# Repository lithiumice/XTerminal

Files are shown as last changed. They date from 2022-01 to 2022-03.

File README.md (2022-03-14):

## 说明
- 模拟器工程在XTerminal\2.Software\XTerminal-ESP32-simulator
- 模拟器工程使用Visual Studio 2019
- 代码工程在XTerminal\2.Software\XTerminal-ESP32-simulator
- 代码工程基于Platformio

#
PCB在项目工程的1.Hardware中，使用Kicad绘制。分为主控板和音频板，两者的硬件连接没有设计好，实际焊接为了便于组装就用了粗一点的飞线把主控板和音频板上的sd卡引脚和音频信号引脚连了起来，我只做了临时的用于验证的一个版本，后面没有心情完善了，只能说这只用于抛砖引玉。
#

#### 主控板焊接
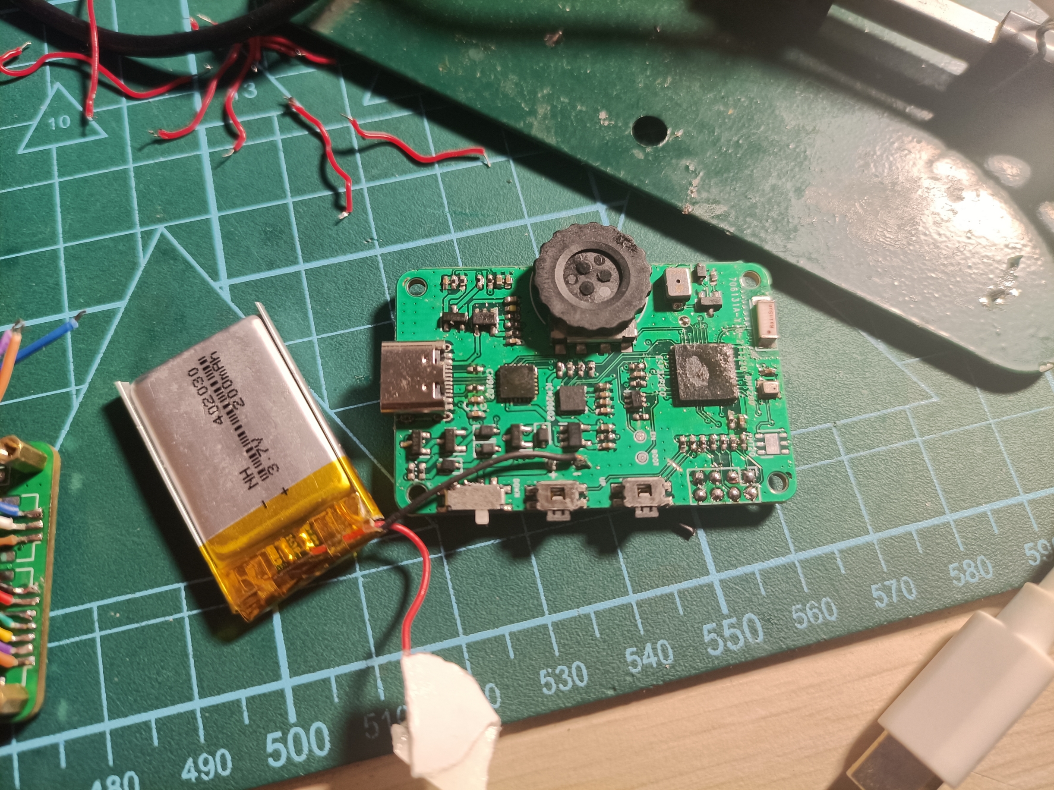
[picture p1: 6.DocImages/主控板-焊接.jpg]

#### 音频板焊接
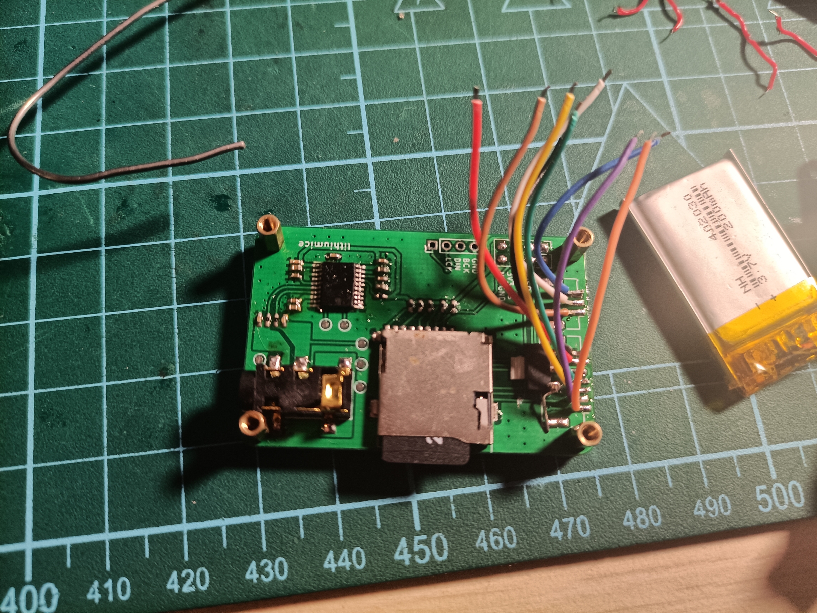
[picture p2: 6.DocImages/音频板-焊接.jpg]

#### 焊接和组装完成的成品效果：
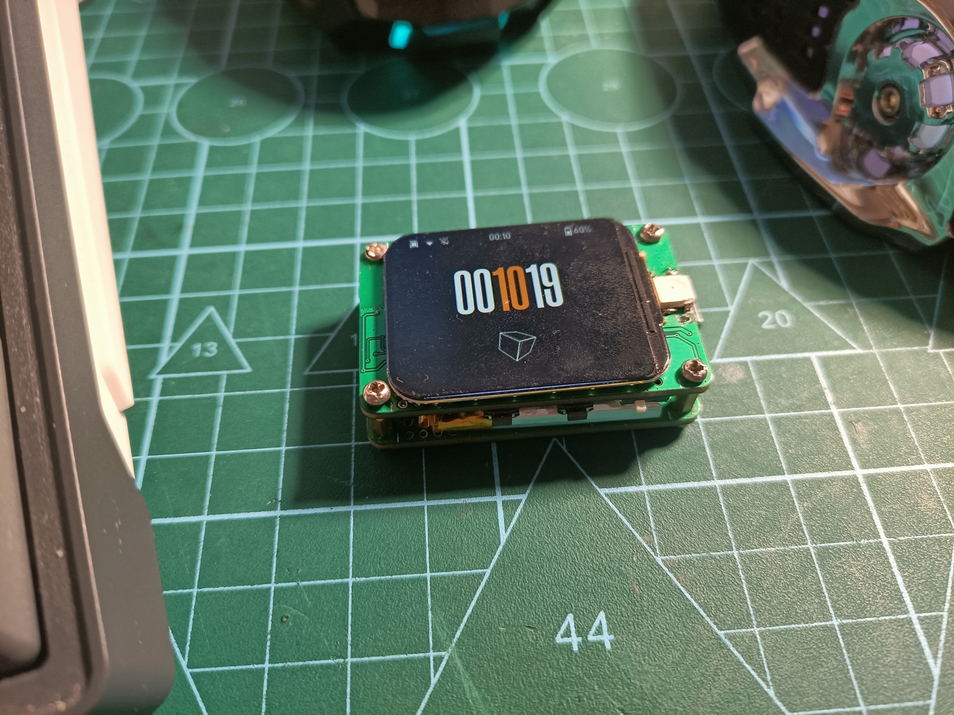
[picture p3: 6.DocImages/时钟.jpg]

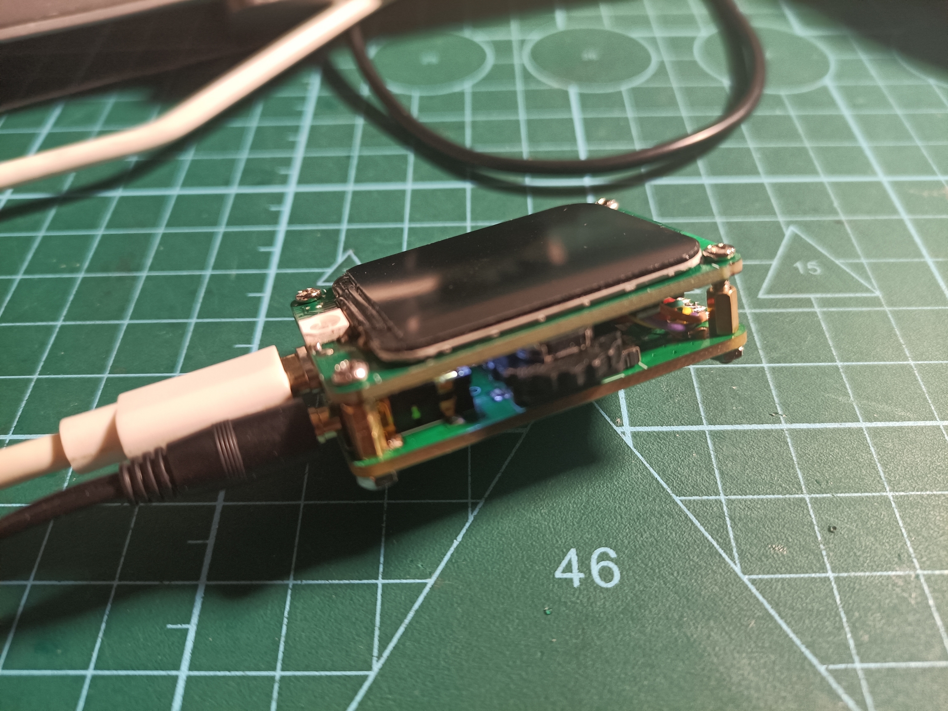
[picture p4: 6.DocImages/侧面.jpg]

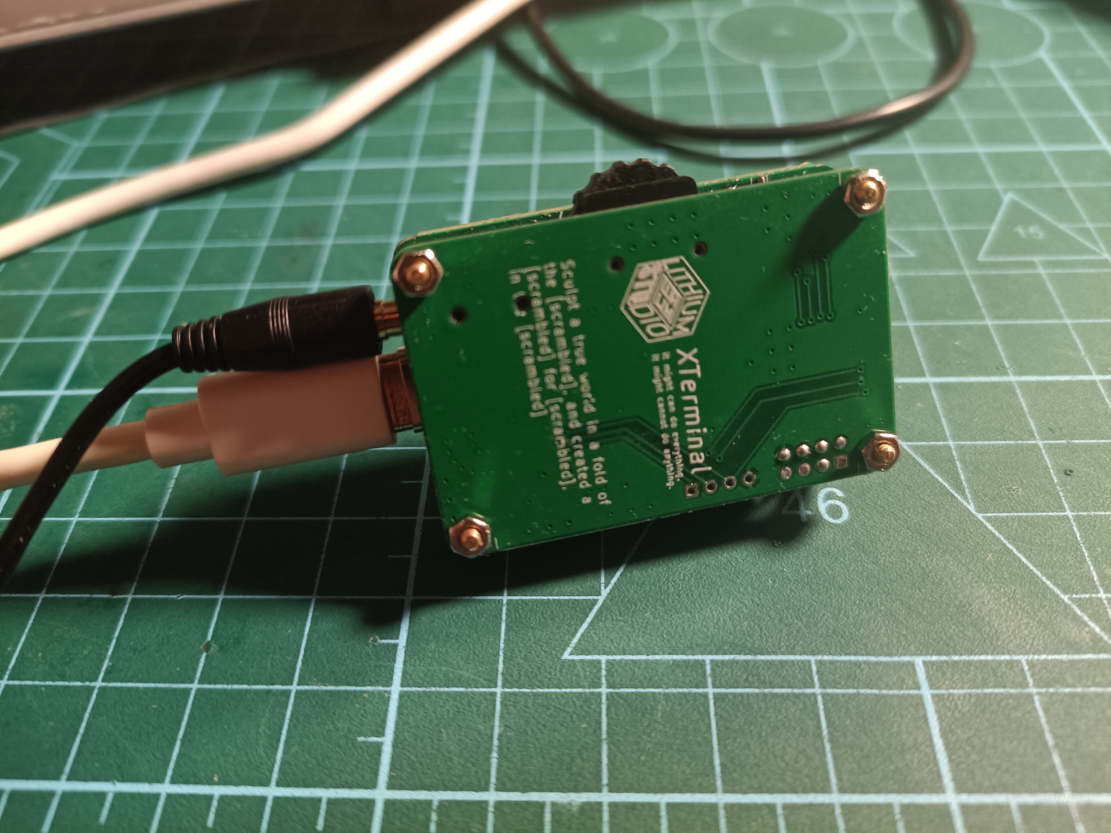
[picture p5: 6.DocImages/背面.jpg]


#### 主界面：（没拍实物图，就只好放模拟器的截图了）
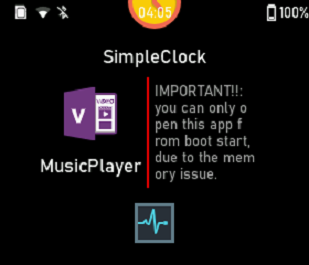
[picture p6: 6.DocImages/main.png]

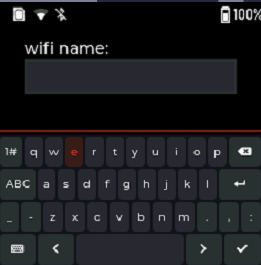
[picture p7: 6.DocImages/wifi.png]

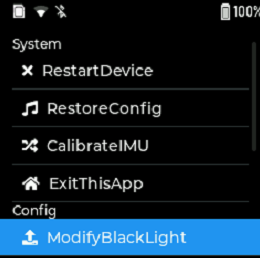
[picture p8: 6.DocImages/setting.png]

#### 天气显示：
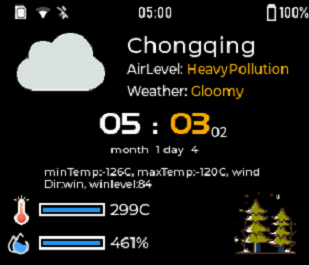
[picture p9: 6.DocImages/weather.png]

#### 几个Arduboy小游戏
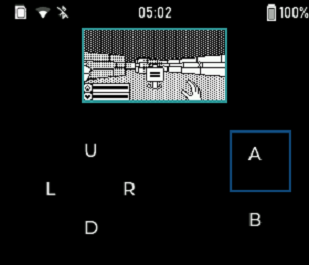
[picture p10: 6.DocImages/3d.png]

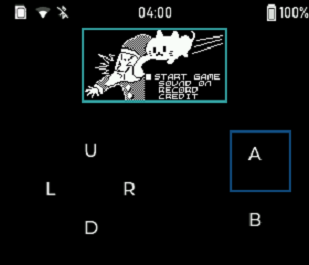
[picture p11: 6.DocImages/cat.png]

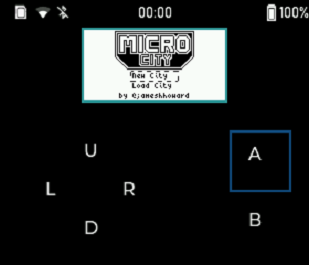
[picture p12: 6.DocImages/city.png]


#### PCB示例
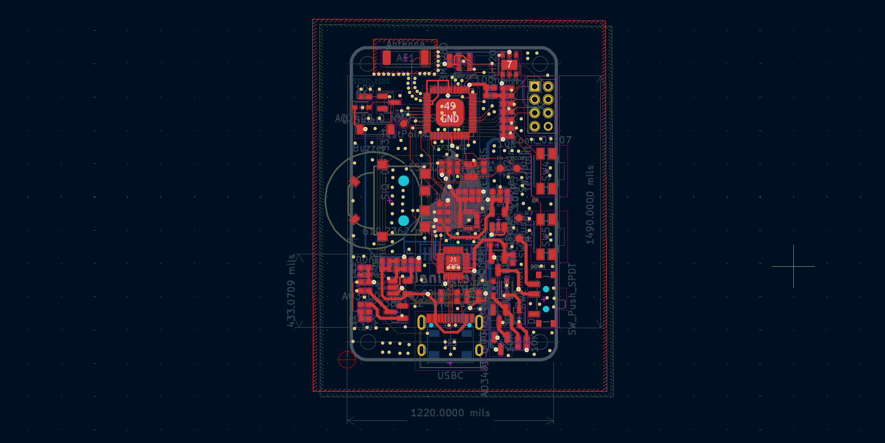
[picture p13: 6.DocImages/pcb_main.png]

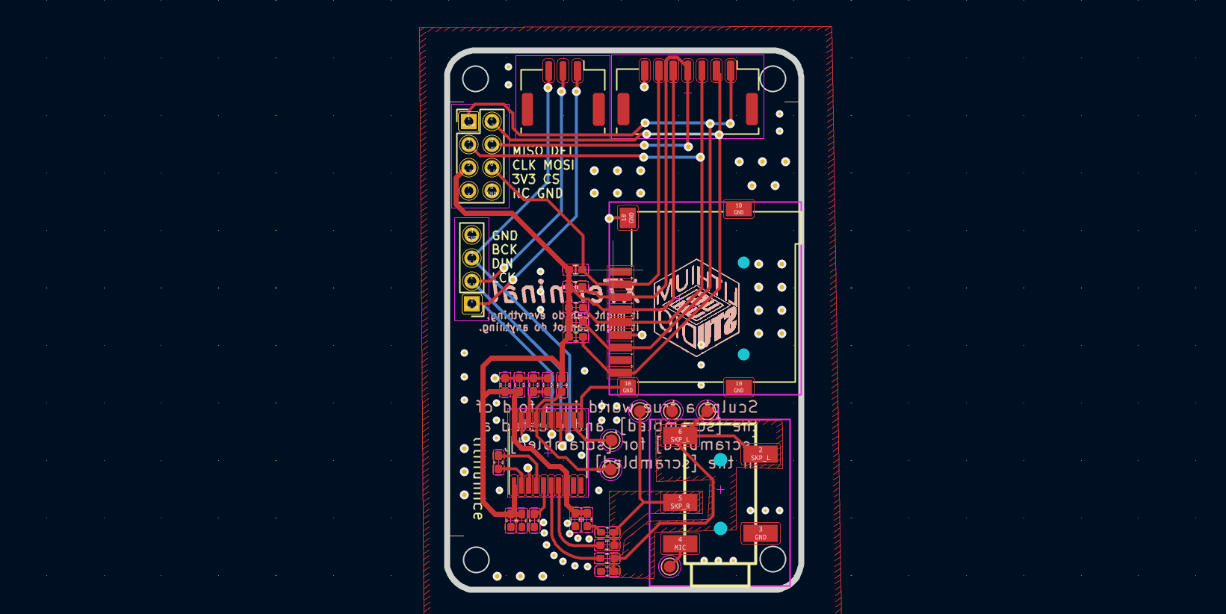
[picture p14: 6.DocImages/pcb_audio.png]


#### 原理图示例
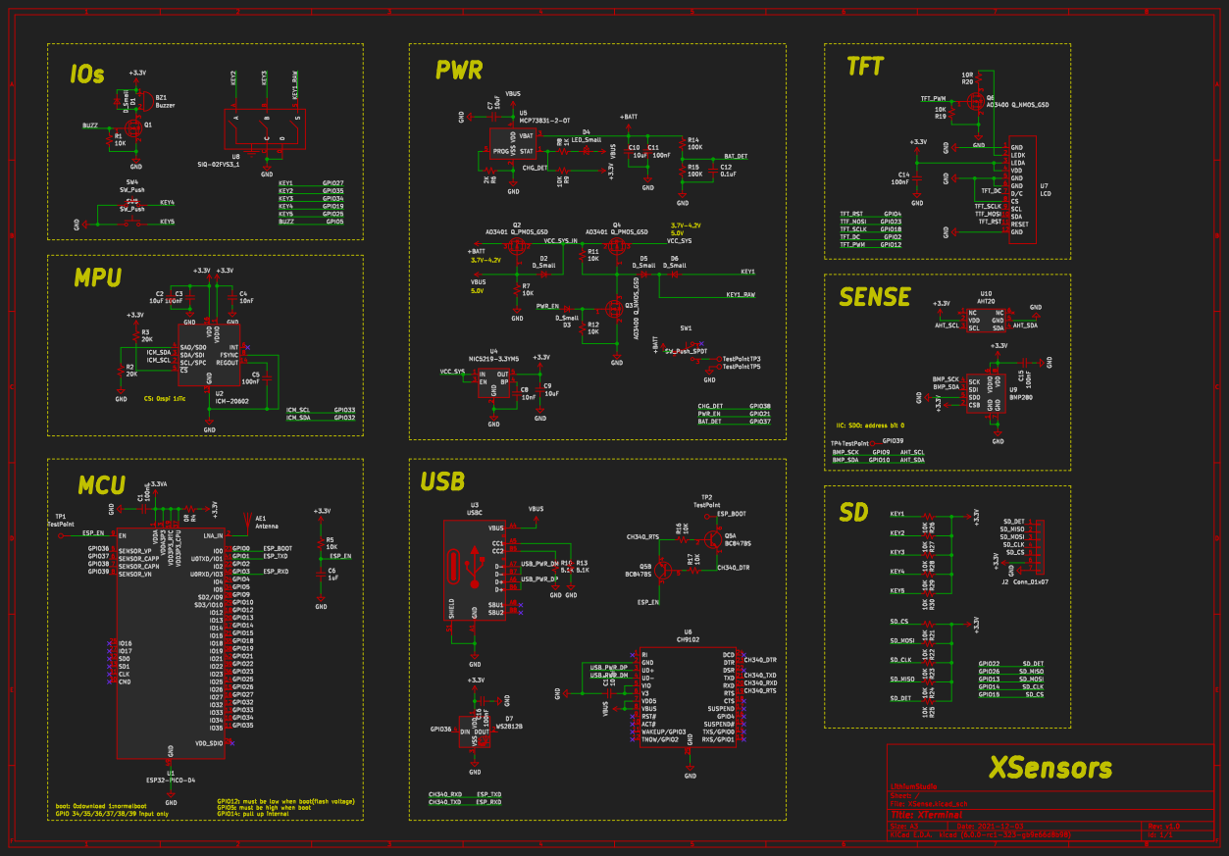
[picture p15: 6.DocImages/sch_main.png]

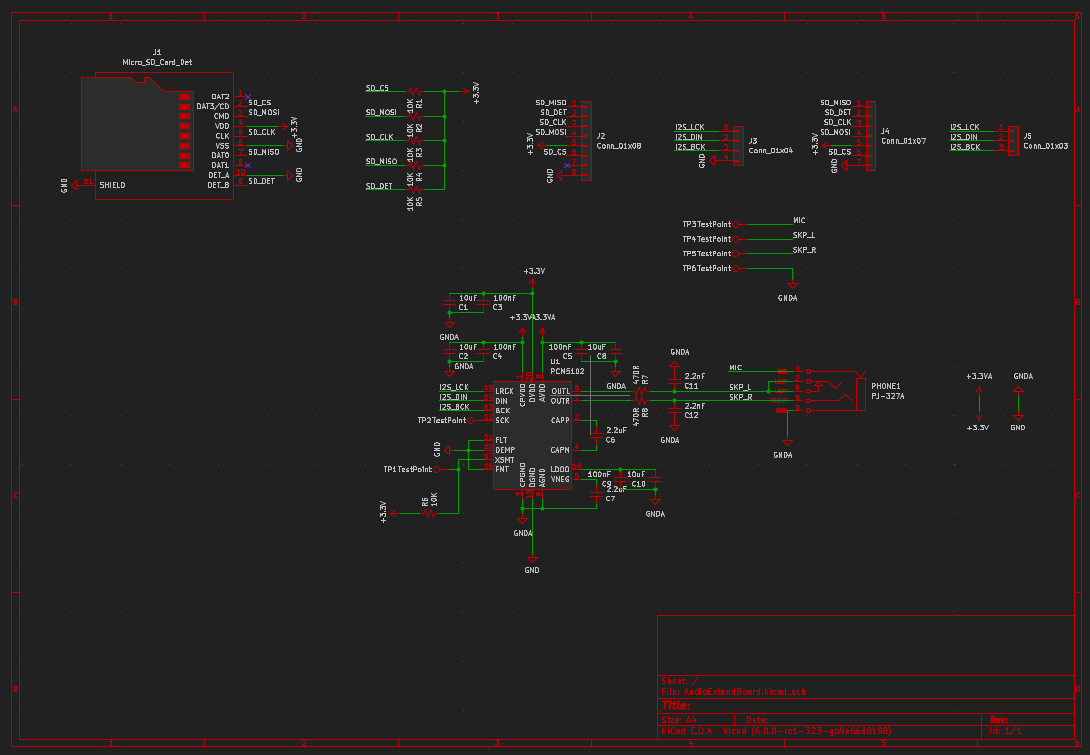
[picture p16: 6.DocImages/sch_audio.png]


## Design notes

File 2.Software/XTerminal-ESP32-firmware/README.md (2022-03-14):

device 0:
esp32-pico-d4
st7789 240x240
encoder keys

device 1:
esp32-pico-d4
st7789 240x280
3axis keys
max30102

devoce 2:
esp-wrover32
ili9341 240x320
pcf keys

devoce 3:
esp-wroom32
st7789 240x320
pcf keys

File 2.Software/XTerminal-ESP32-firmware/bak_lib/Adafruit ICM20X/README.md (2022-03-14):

# Adafruit ICM20X Documentation

This is the Adafruit ICM20X Arduino Library for use with the TDK Invensense ICM20649 and ICM20948 motion sensors.

### Tested and works great with the following Adafruit ICM20X Family Breakout Boards:

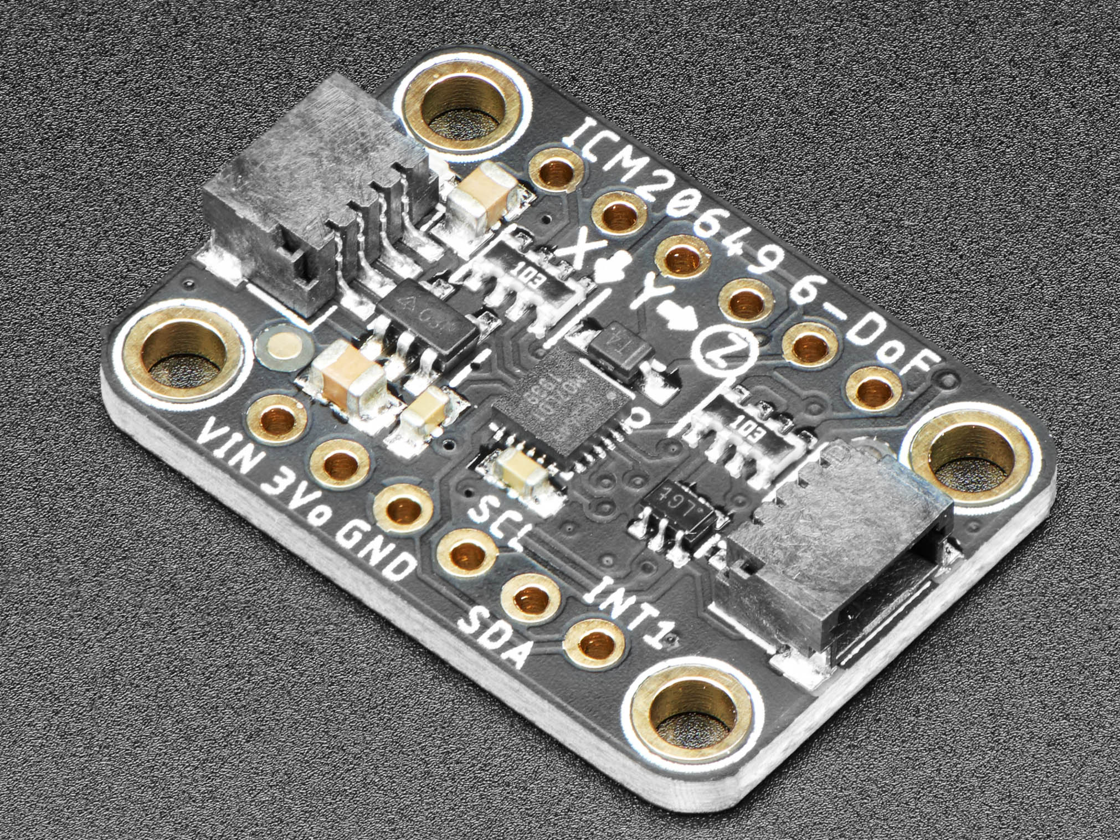
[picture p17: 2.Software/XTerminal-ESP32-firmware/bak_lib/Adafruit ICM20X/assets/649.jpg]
[](https://www.adafruit.com/products/4464)
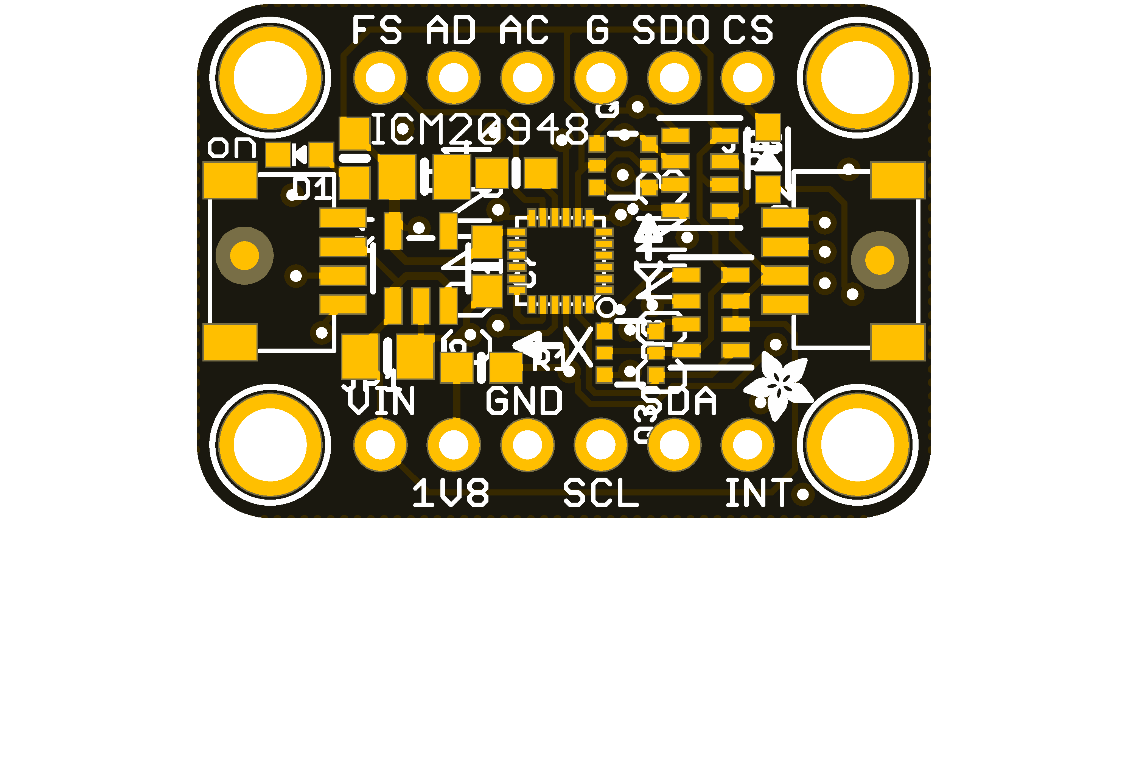
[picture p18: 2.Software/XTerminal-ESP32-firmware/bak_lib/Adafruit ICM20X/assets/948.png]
[](https://www.adafruit.com/products/4554)

#### Compatible sensor breakouts available in the Adafruit store:
* [Adafruit ICM-20649 Wide Range ±30g ±4000dps 6-DoF IMU](https://www.adafruit.com/products/4464)
* [Adafruit ICM-20948 9-DoF IMU](https://www.adafruit.com/products/4554)

Adafruit invests time and resources providing this open source code, please support Adafruit and open-source hardware by purchasing products from Adafruit!

# Installation
To install, use the Arduino Library Manager and search for "Adafruit ICM20X" and install the library.

## Dependencies
 * [Adafruit BusIO](https://github.com/adafruit/Adafruit_BusIO)
 * [Adafruit Unified Sensor Driver](https://github.com/adafruit/Adafruit_Sensor)

# Contributing

Contributions are welcome! Please read our [Code of Conduct](https://github.com/adafruit/Adafruit_ICM20X/blob/master/CODE_OF_CONDUCT.md>)
before contributing to help this project stay welcoming.

## Documentation and doxygen
Documentation is produced by doxygen. Contributions should include documentation for any new code added.

Some examples of how to use doxygen can be found in these guide pages:

https://learn.adafruit.com/the-well-automated-arduino-library/doxygen

https://learn.adafruit.com/the-well-automated-arduino-library/doxygen-tips

## Formatting and clang-format
This library uses [`clang-format`](https://releases.llvm.org/download.html) to standardize the formatting of `.cpp` and `.h` files. 
Contributions should be formatted using `clang-format`:

The `-i` flag will make the changes to the file.
```bash
clang-format -i *.cpp *.h
```
If you prefer to make the changes yourself, running `clang-format` without the `-i` flag will print out a formatted version of the file. You can save this to a file and diff it against the original to see the changes.

Note that the formatting output by `clang-format` is what the automated formatting checker will expect. Any diffs from this formatting will result in a failed build until they are addressed. Using the `-i` flag is highly recommended.

### clang-format resources
  * [Binary builds and source available on the LLVM downloads page](https://releases.llvm.org/download.html)
  * [Documentation and IDE integration](https://clang.llvm.org/docs/ClangFormat.html)

## About this Driver
Written by Bryan Siepert for Adafruit Industries.
BSD license, check license.txt for more information
All text above must be included in any redistribution

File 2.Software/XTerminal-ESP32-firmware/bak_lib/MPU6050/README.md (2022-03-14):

# I2CDEV_MPU6050
I2CDEV MPU-6050 6-axis accelerometer/gyroscope Arduino Library
adapted for Particle devices by Paul Kourany, April 2015

Updated to Particle Libraries v2.0, March 24, 2017

The MPU6050 combines a 3-axis gyroscope and a 3-axis accelerometer on the same silicon die together with
an onboard Digital Motion Processor(DMP) which processes complex 6-axis MotionFusion algorithms.

Original Library
----------------
https://github.com/jrowberg/i2cdevlib/tree/master/Arduino/MPU6050

I2CDevlib Website Link
----------------------
http://www.i2cdevlib.com/devices/mpu6050#source

Installing in the Spark.io Web IDE
----------------------------------

1. Open the Web based IDE on the Spark.io website.
2. Click on the Library button on the left hand side of the IDE. It looks like a little banner or flag...
3. Click "Contribute Library" button at the top of the panel that folded out.
4. Paste "JamesHagerman/MPU6050" into the text field (without quotes, of course).
5. Click "Add Repository".
6. Make sure the main window in the IDE says "Library is valid. Ready to import." at the top.
7. Click "Import".
8. Click "Got it, Proceed" if it asks you. This is basically because the True MPU6050 library is already there (but it's broken otherwise you wouldn't be reading this...)
9. You're done!

Look at the next section to actually use the library in a project. The "Use this example" button doesn't work with this library quite yet.

Using the library on the Spark.io Web IDE
-----------------------------------------

1. Create a new project in the Web based IDE on the Spark.io website. Remember the name for step 6.
2. Click the Library button the left hand side of the IDE. It still looks like a little banner or flag...
3. Select the MPU6050 Library from under the "My Libraries" section.
4. Make sure the version is at least "1.0.1"
5. Click "Include in App"
6. Select the app you just created (or whatever app you wanna use this library in)
7. Click "Add to this App"
8. You're done!

Now you just need some example code, right? You can find a (hopefully) working example at:
```
examples/spark_ide_example.c
```

You'll probably need to modify it pretty heavily to get it to do what you wanna do but at least it's spitting out data now!

Good luck!

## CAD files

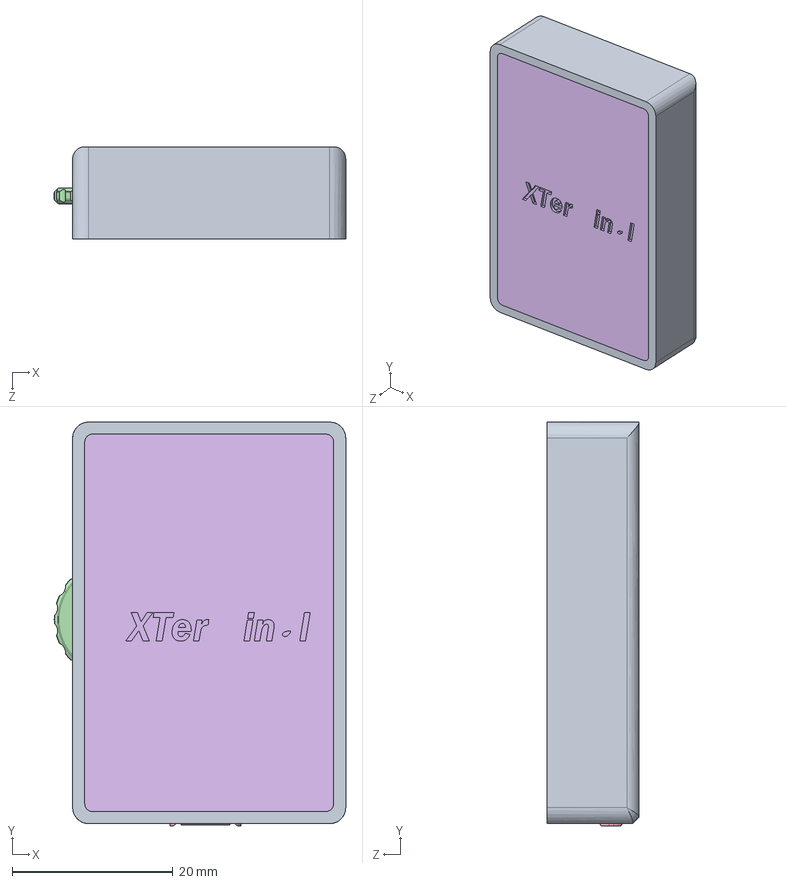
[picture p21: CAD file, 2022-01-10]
3.Mechanic/Xtermianl-280x240-Mechanical/总装配.SLDASM
36.3 x 50.3 x 11.5 mm
PCB外壳
屏幕
电路板
编码器
USB
背板

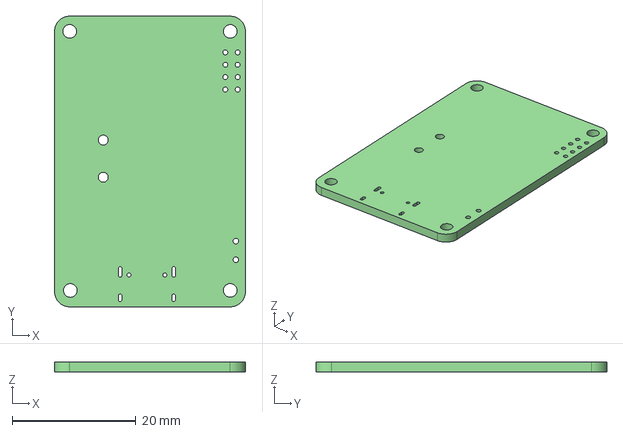
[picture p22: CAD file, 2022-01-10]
1.Hardware/Xtermianl-280x240-Kicad6/XSense.step
30.8 x 46.9 x 1.60 mm

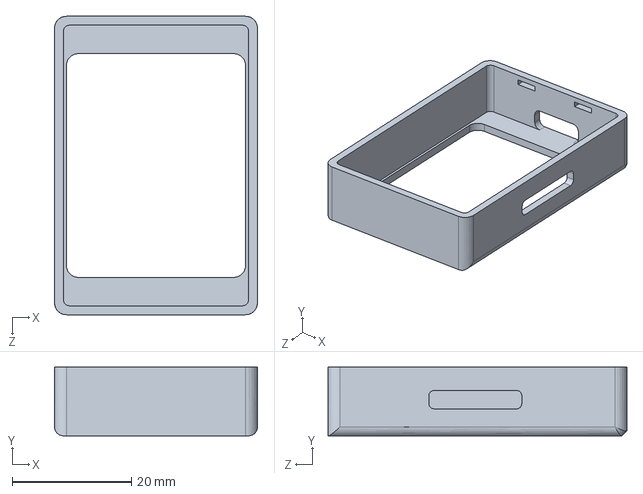
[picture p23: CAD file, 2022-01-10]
3.Mechanic/Xtermianl-280x240-Mechanical/PCB外壳.SLDPRT
34.0 x 11.5 x 50.0 mm

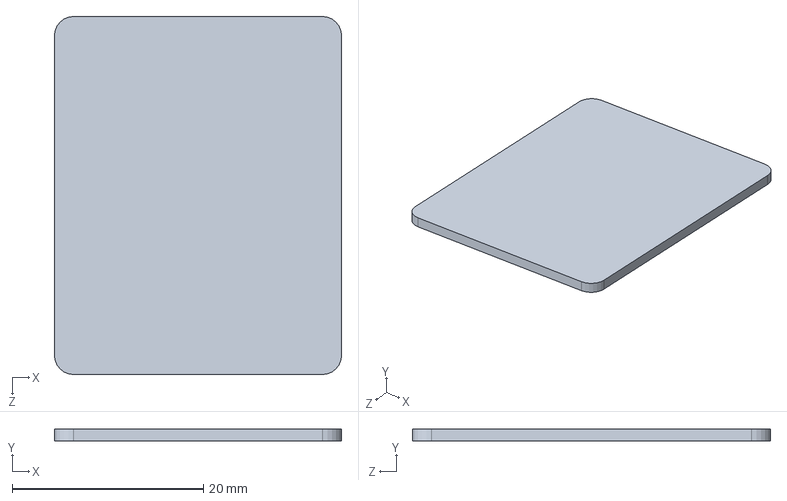
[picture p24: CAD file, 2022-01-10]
3.Mechanic/Xtermianl-280x240-Mechanical/屏幕.SLDPRT
30.0 x 1.30 x 37.4 mm

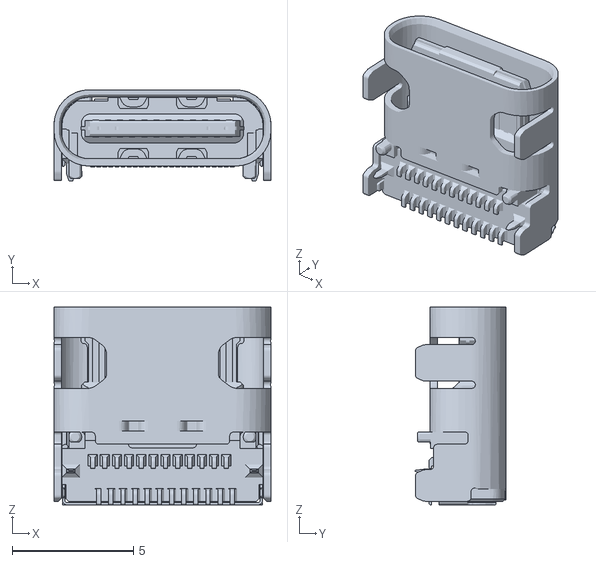
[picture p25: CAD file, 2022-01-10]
3.Mechanic/Xtermianl-280x240-Mechanical/typec.stl
8.94 x 3.77 x 8.15

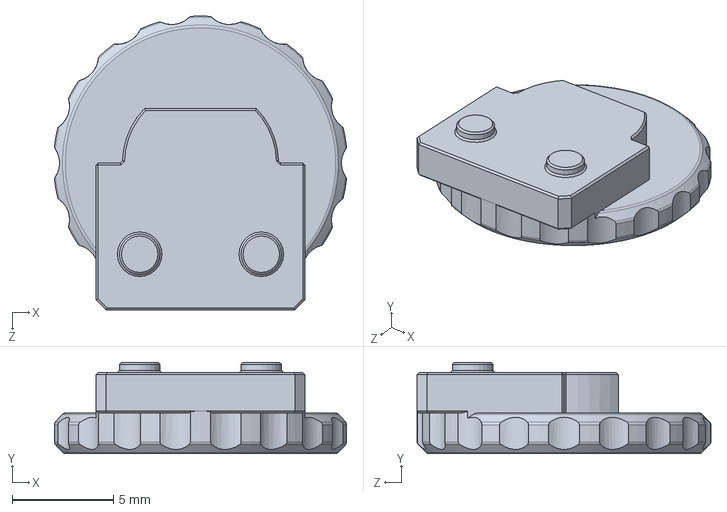
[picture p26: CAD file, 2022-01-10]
3.Mechanic/Xtermianl-280x240-Mechanical/编码器.SLDPRT
14.4 x 4.50 x 14.5 mm

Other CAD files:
3.Mechanic/Xtermianl-280x240-Mechanical/c-2295018-2-b-3d.stp.SLDPRT
3.Mechanic/Xtermianl-280x240-Mechanical/电路板.SLDPRT

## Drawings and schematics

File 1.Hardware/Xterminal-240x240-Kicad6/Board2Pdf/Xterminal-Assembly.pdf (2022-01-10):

BOOT | EN MID + - UP | KEYA DOWN 1 | 2 | 3 | 4 | 5 | 6 1 | 2 | 3 | 4 | 5 | 6 ABCD | ABCD Date: KiCad E.D.A. kicad (6.0.0-rc1-323-gb9e66d8b98) Size: A4 | Rev:

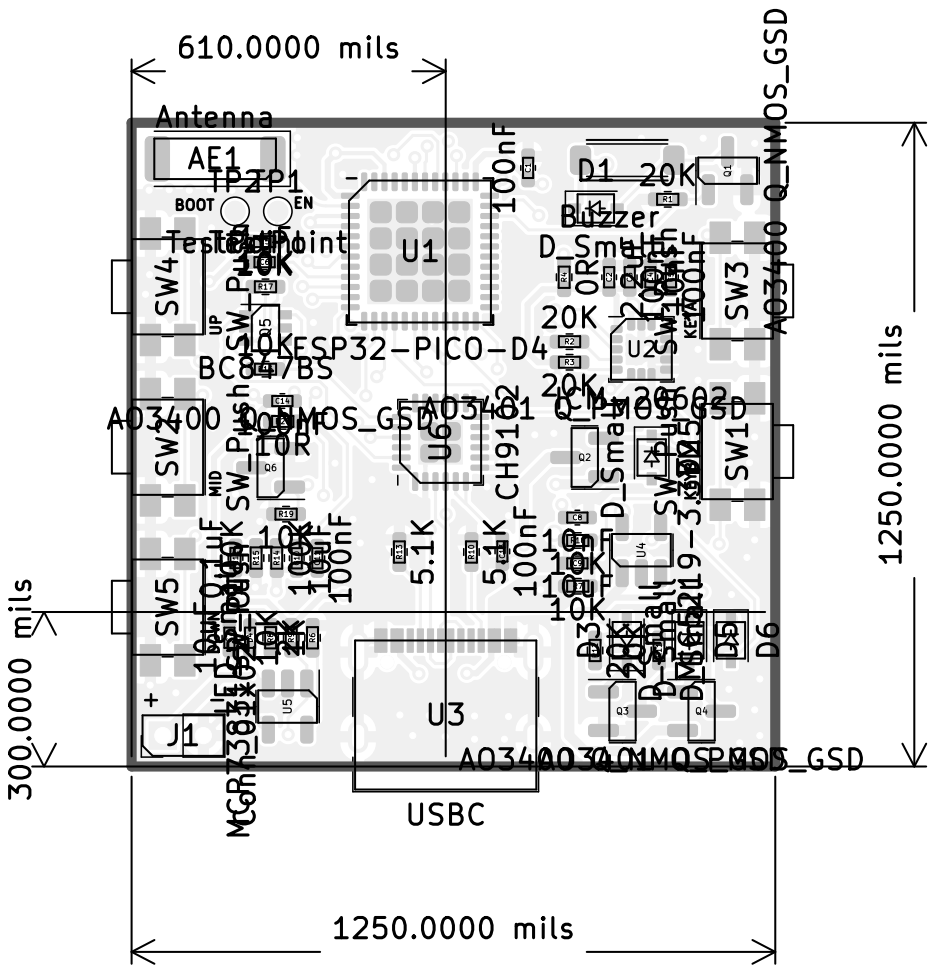
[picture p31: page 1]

1 | 2 | 3 | 4 | 5 | 6

A

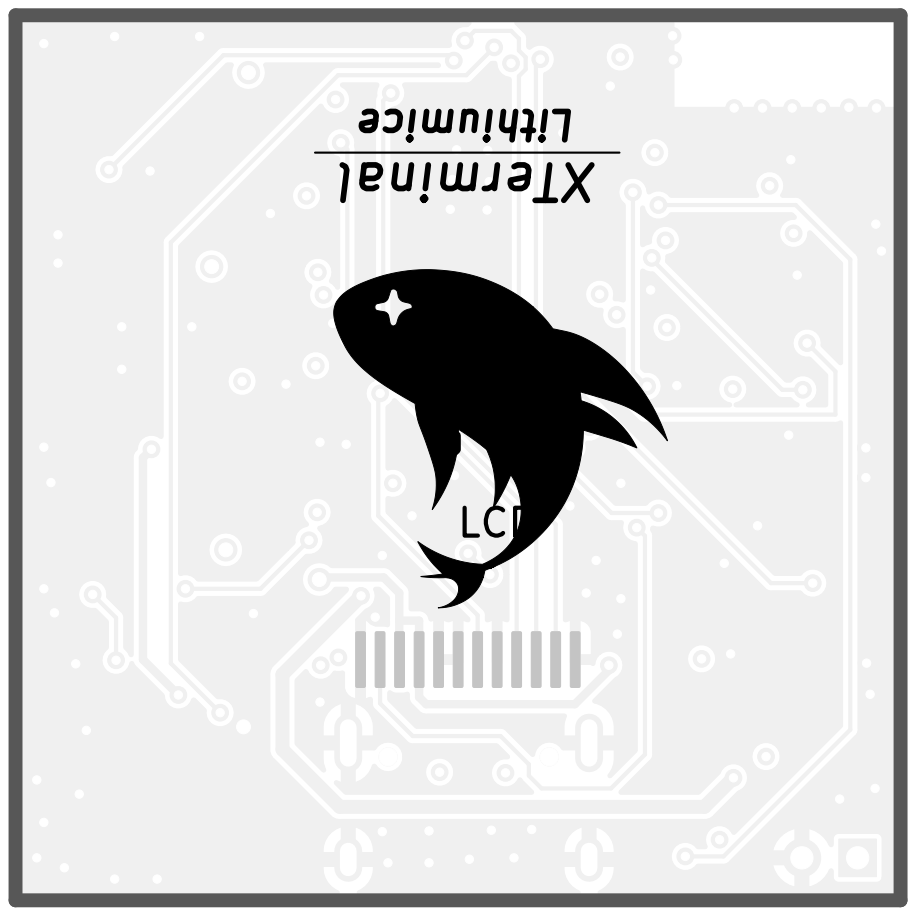
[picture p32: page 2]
D Date: KiCad E.D.A. kicad (6.0.0-rc1-323-gb9e66d8b98) Size: A4; Rev:; Id: 1/1 Title:; File: Xterminal.kicad_pcb; Sheet: Assembly; LCD

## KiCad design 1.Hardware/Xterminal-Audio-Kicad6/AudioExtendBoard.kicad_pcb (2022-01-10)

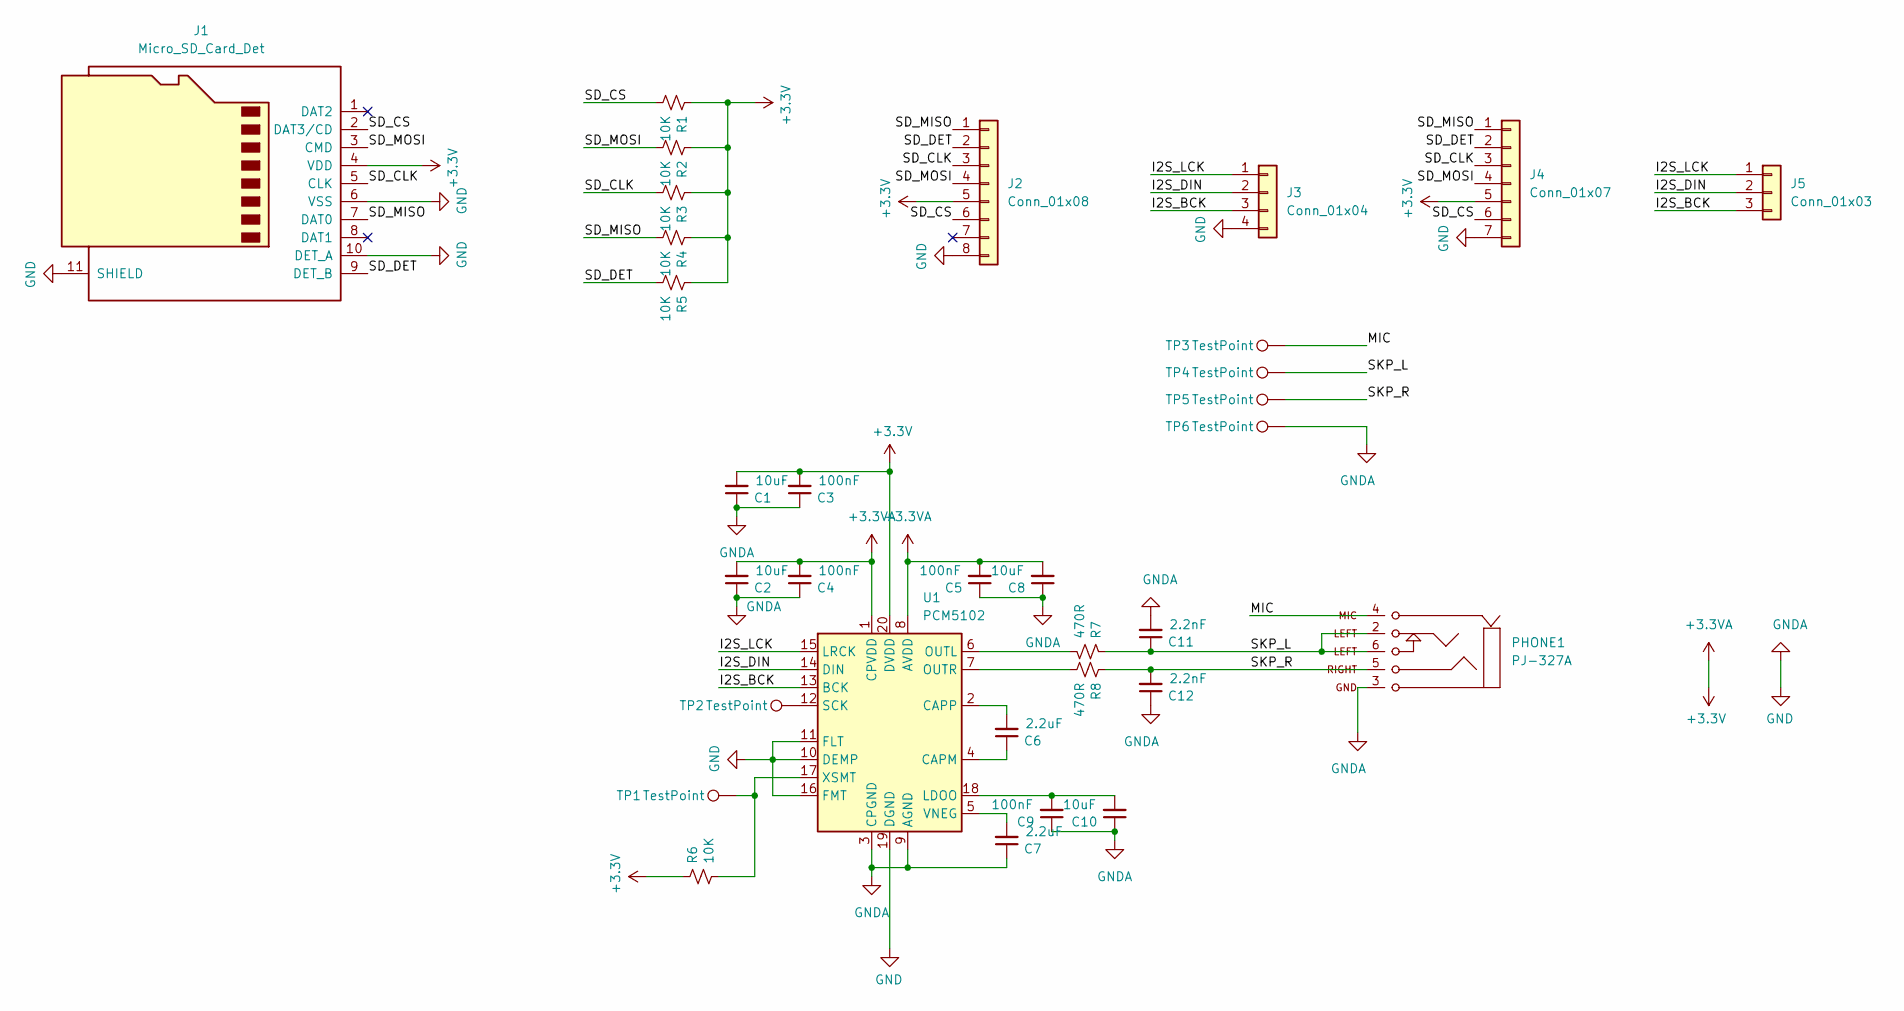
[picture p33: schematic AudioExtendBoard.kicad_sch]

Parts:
C1, C2, C8, C10: 10uF; C_0402_1005Metric_Pad0.74x0.62mm_HandSolder
C3, C4, C5, C9: 100nF; C_0402_1005Metric_Pad0.74x0.62mm_HandSolder
C6, C7: 2.2uF; C_0402_1005Metric_Pad0.74x0.62mm_HandSolder
C11, C12: 2.2nF; C_0402_1005Metric_Pad0.74x0.62mm_HandSolder
J1: Micro_SD_Card_Det; TF-SMD_TF-015
J2: Conn_01x08; PinHeader_2x04_P2.00mm_Vertical
J3: Conn_01x04; PinHeader_1x04_P2.00mm_Vertical
J4: Conn_01x07; Molex_CLIK-Mate_502382-0770_1x07-1MP_P1.25mm_Vertical
J5: Conn_01x03; Molex_CLIK-Mate_502382-0370_1x03-1MP_P1.25mm_Vertical
PHONE1: PJ-327A; PJ327A
R1, R2, R3, R4, R5, R6: 10K; R_0402_1005Metric_Pad0.72x0.64mm_HandSolder
R7, R8: 470R; R_0402_1005Metric_Pad0.72x0.64mm_HandSolder
TP1, TP2, TP3, TP4, TP5, TP6: TestPoint; TestPoint_Pad_D1.0mm
U1: PCM5102; TSSOP-20_4.4x6.5mm_P0.65mm

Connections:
+3.3VA: C1.2, C2.2, C3.2, C4.2, C5.2, C8.2, J1.4 (VDD), J2.5, J4.5, R1.1, R2.1, R3.1, R4.1, R5.1, R6.1, U1.1 (CPVDD), U1.8 (AVDD), U1.20 (DVDD)
/I2S_BCK: J3.3, J5.3, U1.13 (BCK)
/I2S_DIN: J3.2, J5.2, U1.14 (DIN)
/I2S_LCK: J3.1, J5.1, U1.15 (LRCK)
/MIC: PHONE1.4, TP3.1
/SD_CLK: J1.5 (CLK), J2.3, J4.3, R3.2
/SD_CS: J1.2 (DAT3/CD), J2.6, J4.6, R1.2
/SD_DET: J1.9 (DET_B), J2.2, J4.2, R5.2
/SD_MISO: J1.7 (DAT0), J2.1, J4.1, R4.2
/SD_MOSI: J1.3 (CMD), J2.4, J4.4, R2.2
/SKP_L: C11.1, PHONE1.2, PHONE1.6, R7.1, TP4.1
/SKP_R: C12.2, PHONE1.5, R8.1, TP5.1
GND: C1.1, C2.1, C3.1, C4.1, C5.1, C7.1, C8.1, C9.1, C10.1, C11.2, C12.1, J1.6 (VSS), J1.10 (DET_A), J1.11 (SHIELD), J2.8, J3.4, J4.7, PHONE1.3 (1), TP6.1, U1.3 (CPGND), U1.9 (AGND), U1.10 (DEMP), U1.11 (FLT), U1.16 (FMT), U1.19 (DGND)
unnamed: C6.1, U1.4 (CAPM)
unnamed: C6.2, U1.2 (CAPP)
unnamed: C7.2, U1.5 (VNEG)
unnamed: C9.2, C10.2, U1.18 (LDOO)
unnamed: R6.2, TP1.1, U1.17 (XSMT)
unnamed: R7.2, U1.6 (OUTL)
unnamed: R8.2, U1.7 (OUTR)
unnamed: TP2.1, U1.12 (SCK)

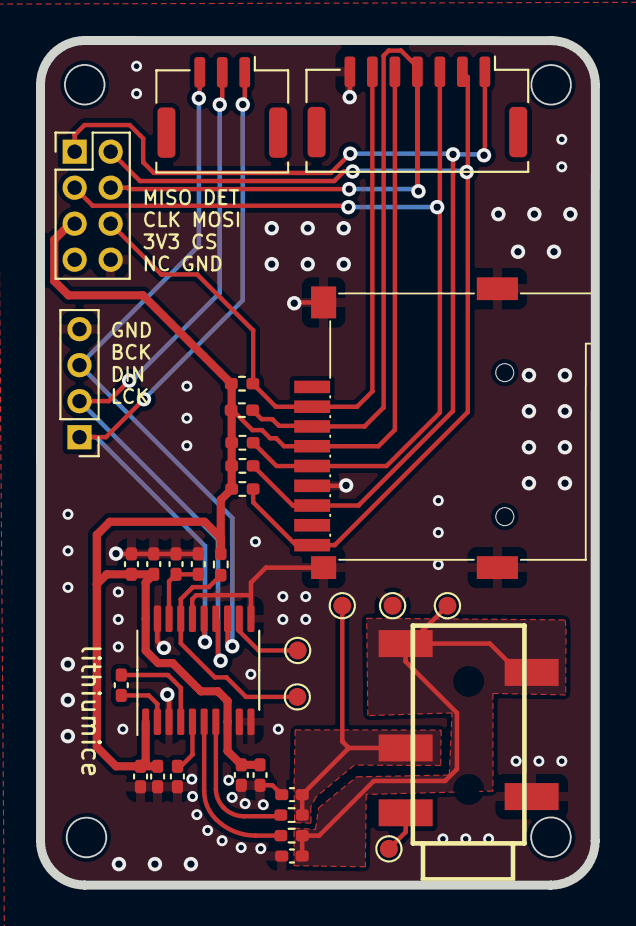
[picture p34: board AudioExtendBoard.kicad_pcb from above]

Board: 2 copper layers, 30.8 x 46.9 mm, 33 parts (0 on the bottom side), 21 nets.

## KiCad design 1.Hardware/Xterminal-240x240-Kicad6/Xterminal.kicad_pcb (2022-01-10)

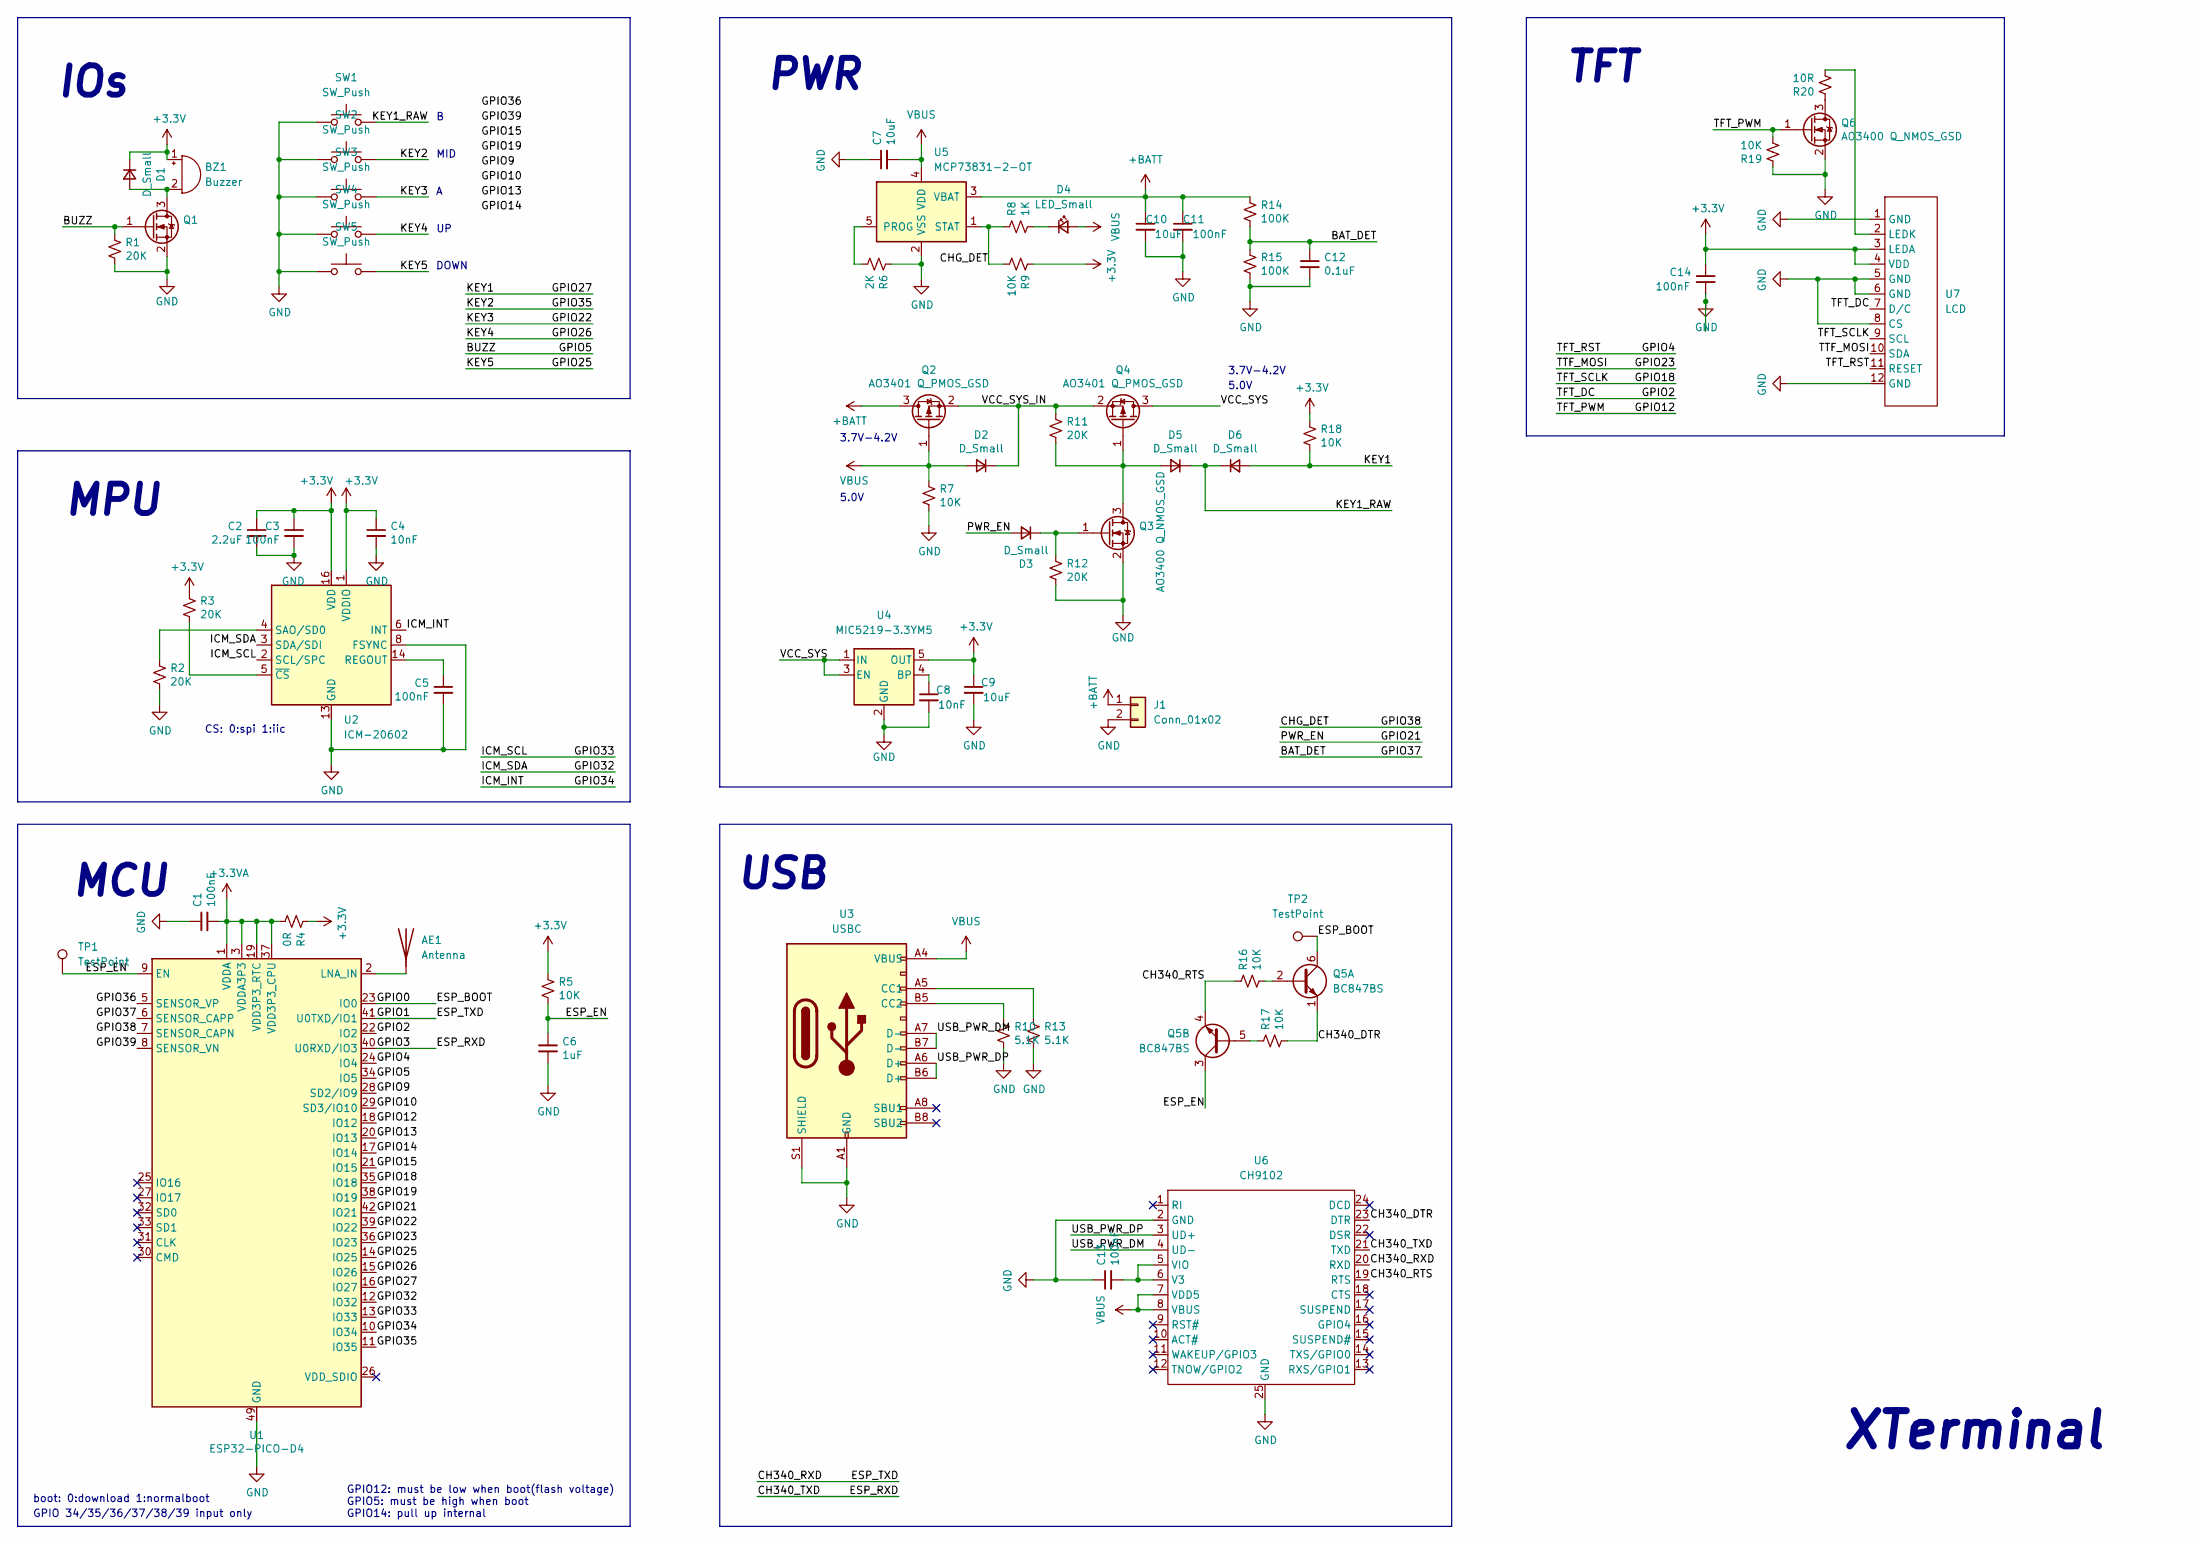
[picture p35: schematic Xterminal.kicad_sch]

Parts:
AE1: Antenna; Johanson_2450AT43F0100
BZ1: Buzzer; DET402
C1, C3, C5, C11, C13, C14: 100nF; C_0402_1005Metric_Pad0.74x0.62mm_HandSolder
C2: 2.2uF; C_0402_1005Metric_Pad0.74x0.62mm_HandSolder
C4, C8: 10nF; C_0402_1005Metric_Pad0.74x0.62mm_HandSolder
C6: 1uF; C_0402_1005Metric_Pad0.74x0.62mm_HandSolder
C7, C9, C10: 10uF; C_0402_1005Metric_Pad0.74x0.62mm_HandSolder
C12: 0.1uF; C_0402_1005Metric_Pad0.74x0.62mm_HandSolder
D1, D2, D3, D5, D6: D_Small; D_SOD-323
D4: LED_Small; C_0402_1005Metric_Pad0.74x0.62mm_HandSolder
J1: Conn_01x02; PinHeader_1x02_P2.00mm_Vertical
Q1, Q3, Q6: AO3400 Q_NMOS_GSD; SOT-23
Q2, Q4: AO3401 Q_PMOS_GSD; SOT-23
Q5: BC847BS; SOT-363_SC-70-6
R1, R2, R3, R11, R12: 20K; R_0402_1005Metric_Pad0.72x0.64mm_HandSolder
R4: 0R; R_0402_1005Metric_Pad0.72x0.64mm_HandSolder
R5, R7, R9, R16, R17, R18, R19: 10K; R_0402_1005Metric_Pad0.72x0.64mm_HandSolder
R6: 2K; R_0402_1005Metric_Pad0.72x0.64mm_HandSolder
R8: 1K; R_0402_1005Metric_Pad0.72x0.64mm_HandSolder
R10, R13: 5.1K; R_0402_1005Metric_Pad0.72x0.64mm_HandSolder
R14, R15: 100K; R_0402_1005Metric_Pad0.72x0.64mm_HandSolder
R20: 10R; R_0402_1005Metric_Pad0.72x0.64mm_HandSolder
SW1, SW2, SW3, SW4, SW5: SW_Push; Panasonic_EVQPUJ_EVQPUA
TP1, TP2: TestPoint; TestPoint_Pad_D1.0mm
U1: ESP32-PICO-D4; QFN-48-1EP_7x7mm_P0.5mm_EP5.15x5.15mm
U2: ICM-20602; LGA-16_3x3mm_P0.5mm_LayoutBorder3x5y
U3: USBC; USB_C_Receptacle_XKB_U262-16XN-4BVC11
U4: MIC5219-3.3YM5; SOT-23-5
U5: MCP73831-2-OT; SOT-23-5
U6: CH9102; QFN-24-1EP_4x4mm_P0.5mm_EP2.15x2.15mm
U7: LCD; LCD-ST7789-1.54-12PINS

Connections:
+3.3VA: C1.2, R4.2, U1.1 (VDDA), U1.3 (VDDA3P3), U1.4 (VDDA3P3), U1.19 (VDD3P3_RTC), U1.37 (VDD3P3_CPU), U1.43 (VDDA), U1.46 (VDDA)
+3V3: BZ1.1 (-), C2.1, C3.1, C4.1, C9.1, C14.1, D1.1 (K), R3.1, R4.1, R5.1, R9.1, R18.1, U2.1 (VDDIO), U2.16 (VDD), U4.5 (OUT), U7.3 (LEDA), U7.4 (VDD)
+BATT: C10.1, C11.1, J1.1, Q2.3 (D), R14.1, U5.3 (VBAT)
/BAT_DET: C12.1, R14.2, R15.1, U1.6 (SENSOR_CAPP)
/BUZZ: Q1.1 (G), R1.1, U1.34 (IO5)
/CH340_DTR: Q5.1 (E1), R17.2, U6.23 (DTR)
/CH340_RTS: Q5.4 (E2), R16.1, U6.19 (RTS)
/CH340_RXD: U1.41 (U0TXD/IO1), U6.20 (RXD)
/CH340_TXD: U1.40 (U0RXD/IO3), U6.21 (TXD)
/CHG_DET: R8.1, R9.2, U1.7 (SENSOR_CAPN), U5.1 (STAT)
/ESP_BOOT: Q5.6 (C1), TP2.1, U1.23 (IO0)
/ESP_EN: C6.1, Q5.3 (C2), R5.2, TP1.1, U1.9 (EN)
/GPIO2: U1.22 (IO2), U7.7 (D/C)
/GPIO4: U1.24 (IO4), U7.11 (RESET)
/GPIO9: U1.28 (SD2/IO9)
/GPIO10: U1.29 (SD3/IO10)
/GPIO12: Q6.1 (G), R19.2, U1.18 (IO12)
/GPIO13: U1.20 (IO13)
/GPIO14: U1.17 (IO14)
/GPIO15: U1.21 (IO15)
/GPIO18: U1.35 (IO18), U7.9 (SCL)
/GPIO19: U1.38 (IO19)
/GPIO21: D3.2 (A), U1.42 (IO21)
/GPIO22: SW3.2, U1.39 (IO22)
/GPIO23: U1.36 (IO23), U7.10 (SDA)
/GPIO25: SW5.2, U1.14 (IO25)
/GPIO26: SW4.2, U1.15 (IO26)
/GPIO27: D6.2 (A), R18.2, U1.16 (IO27)
/GPIO32: U1.12 (IO32), U2.3 (SDA/SDI)
/GPIO33: U1.13 (IO33), U2.2 (SCL/SPC)
/GPIO34: U1.10 (IO34), U2.6 (INT)
/GPIO35: SW2.2, U1.11 (IO35)
/GPIO36: U1.5 (SENSOR_VP)
/GPIO39: U1.8 (SENSOR_VN)
/KEY1_RAW: D5.1 (K), D6.1 (K), SW1.2
/USB_PWR_DM: U3.A7 (D-), U3.B7 (D-), U6.4 (UD-)
/USB_PWR_DP: U3.A6 (D+), U3.B6 (D+), U6.3 (UD+)
GND: C1.1, C2.2, C3.2, C4.2, C5.2, C6.2, C7.1, C8.2, C9.2, C10.2, C11.2, C12.2, C13.1, C14.2, J1.2, Q1.2 (S), Q3.2 (S), Q6.2 (S), R1.2, R2.2, R6.1, R7.2, R10.2, R12.2, R13.2, R15.2, R19.1, SW1.1, SW2.1, SW3.1, SW4.1, SW5.1, U1.49 (GND), U2.8 (FSYNC), U2.9 (GND), U2.10 (GND), U2.11 (GND), U2.12 (GND), U2.13 (GND), U2.15 (GND), U3.A1 (GND), U3.A12 (GND), U3.B1 (GND), U3.B12 (GND), U3.S1 (SHIELD), U4.2 (GND), U5.2 (VSS), U6.2 (GND), U6.25 (GND), U7.1 (GND), U7.5 (GND), U7.6 (GND), U7.8 (CS), U7.12 (GND)
unnamed: AE1.1 (A), U1.2 (LNA_IN)
unnamed: BZ1.2 (+), D1.2 (A), Q1.3 (D)
unnamed: C5.1, U2.14 (REGOUT)
unnamed: C8.1, U4.4 (BP)
unnamed: C13.2, U6.5 (VIO), U6.6 (V3)
unnamed: D3.1 (K), Q3.1 (G), R12.1
unnamed: D4.1 (K), R8.2
unnamed: D5.2 (A), Q3.3 (D), Q4.1 (G), R11.2
unnamed: Q5.2 (B1), R16.2
unnamed: Q5.5 (B2), R17.1
unnamed: Q6.3 (D), R20.1
unnamed: R2.1, U2.4 (SAO/SD0)
unnamed: R3.2, U2.5 (~CS)
unnamed: R6.2, U5.5 (PROG)
unnamed: R10.1, U3.B5 (CC2)
unnamed: R13.1, U3.A5 (CC1)
unnamed: R20.2, U7.2 (LEDK)
VBUS: C7.2, D2.2 (A), D4.2 (A), Q2.1 (G), R7.1, U3.A4 (VBUS), U3.A9 (VBUS), U3.B4 (VBUS), U3.B9 (VBUS), U5.4 (VDD), U6.7 (VDD5), U6.8 (VBUS)

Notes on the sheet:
MPU
GPIO 34/35/36/37/38/39 input only
5.0V
3.7V-4.2V
GPIO12: must be low when boot(flash voltage) GPIO5: must be high when boot GPIO14: pull up internal
XTerminal
MCU
DOWN
USB
PWR
IOs
boot: 0:download 1:normalboot
MID
TFT
CS: 0:spi 1:iic

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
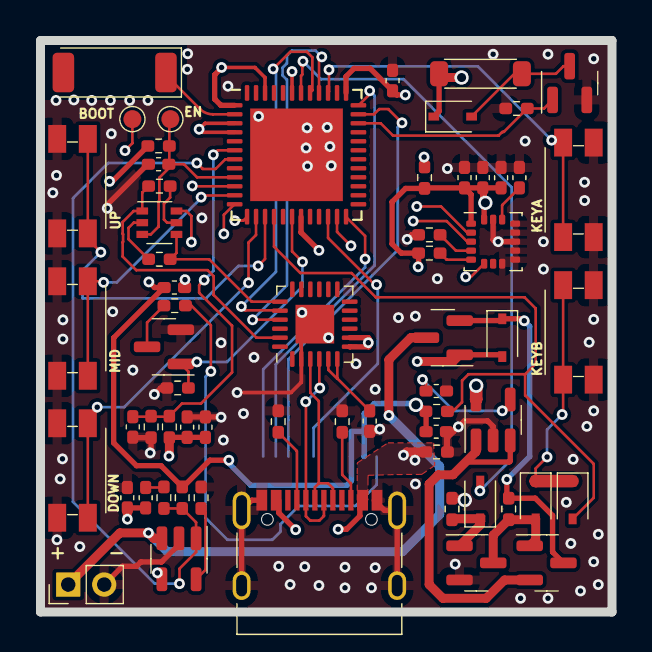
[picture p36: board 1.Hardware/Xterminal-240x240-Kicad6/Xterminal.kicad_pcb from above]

Board: 4 copper layers, 31.8 x 31.8 mm, 63 parts (1 on the bottom side), 50 nets.

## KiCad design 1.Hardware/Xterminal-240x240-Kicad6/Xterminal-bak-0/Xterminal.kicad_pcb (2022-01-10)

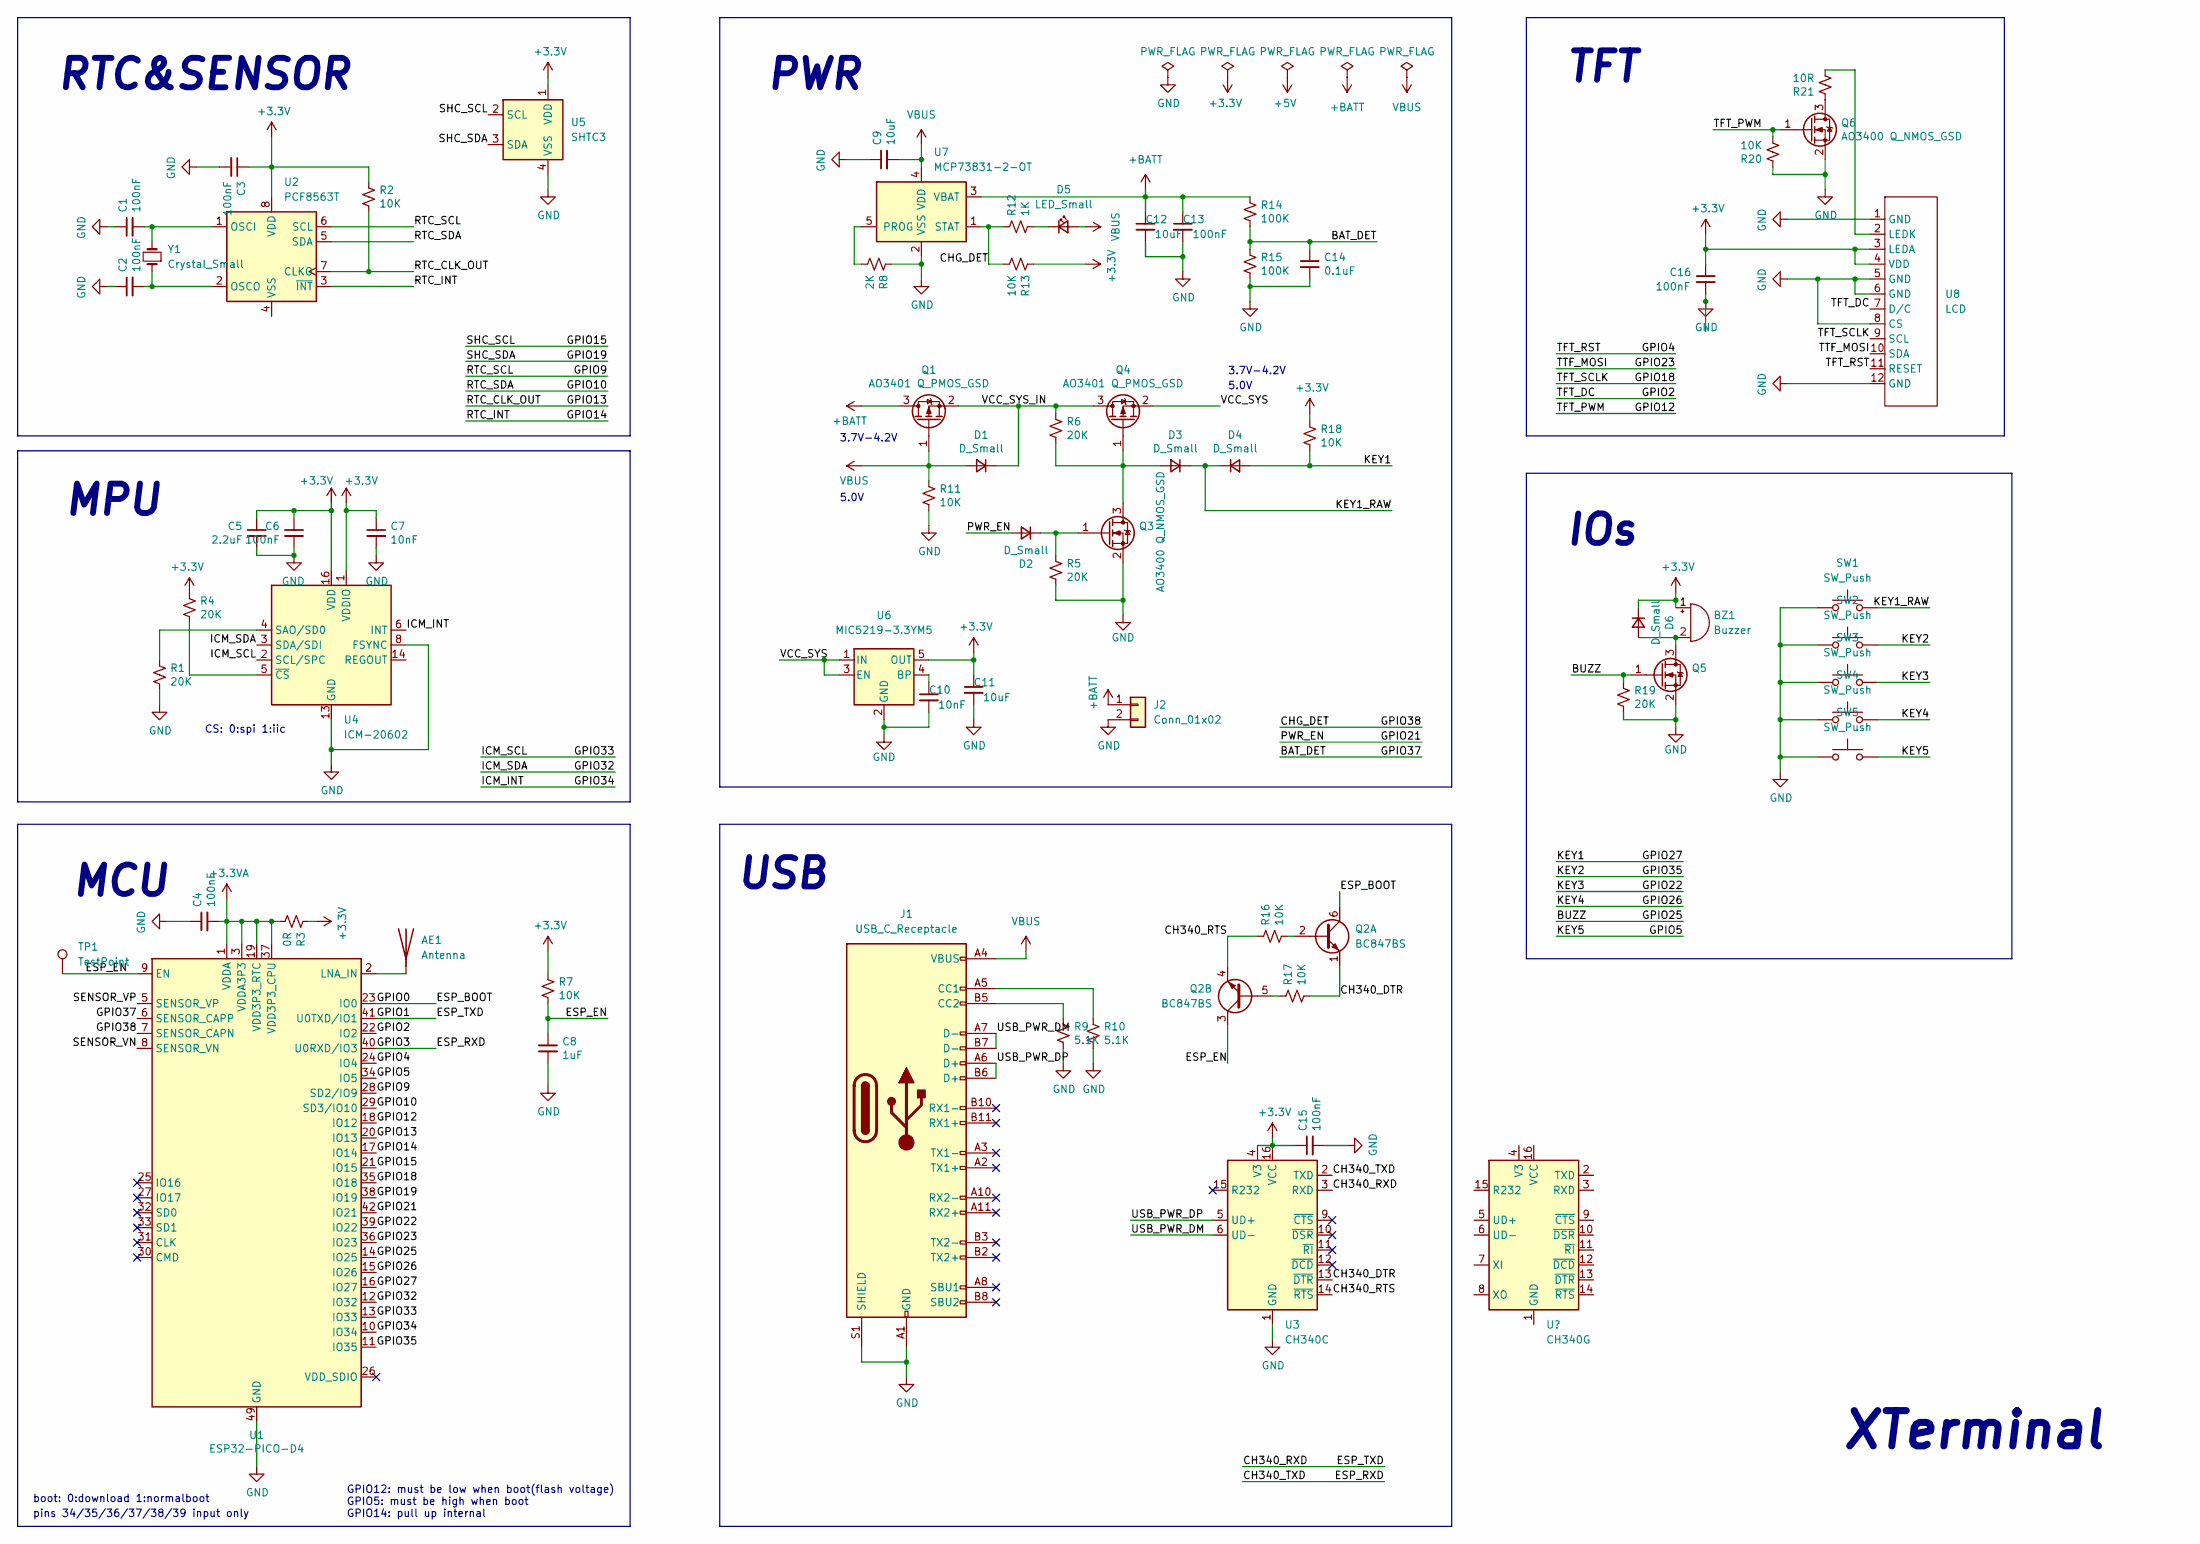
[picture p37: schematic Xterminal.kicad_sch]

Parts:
AE1: Antenna; Johanson_2450AT43F0100
BZ1: Buzzer; MagneticBuzzer_Kobitone_254-EMB84Q-RO
C1, C2, C3, C4, C6, C13, C15, C16: 100nF; C_0603_1608Metric
C5: 2.2uF; C_0603_1608Metric
C7, C10: 10nF; C_0603_1608Metric
C8: 1uF; C_0603_1608Metric
C9, C11, C12: 10uF; C_0603_1608Metric
C14: 0.1uF; C_0603_1608Metric
D1, D2, D3, D4, D6: D_Small; D_SOD-323
D5: LED_Small; C_0603_1608Metric
J1: USB_C_Receptacle; USB_C_Receptacle_XKB_U262-16XN-4BVC11
J2: Conn_01x02; PinHeader_1x02_P2.00mm_Vertical
Q1, Q4: AO3401 Q_PMOS_GSD; SOT-23
Q2: BC847BS; SOT-363_SC-70-6
Q3, Q5, Q6: AO3400 Q_NMOS_GSD; SOT-23
R1, R4, R5, R6, R19: 20K; R_0603_1608Metric
R2, R7, R11, R13, R16, R17, R18, R20: 10K; R_0603_1608Metric
R3: 0R; R_0603_1608Metric
R8: 2K; R_0603_1608Metric
R9, R10: 5.1K; R_0603_1608Metric
R12: 1K; R_0603_1608Metric
R14, R15: 100K; R_0603_1608Metric
R21: 10R; R_0603_1608Metric
SW1, SW2, SW3, SW4, SW5: SW_Push; Panasonic_EVQPUJ_EVQPUA
TP1: TestPoint; TestPoint_Pad_D1.0mm
U1: ESP32-PICO-D4; QFN-48-1EP_7x7mm_P0.5mm_EP5.3x5.3mm
U2: PCF8563T; SOIC-8_3.9x4.9mm_P1.27mm
U3: CH340C; SOIC-16_3.9x9.9mm_P1.27mm
U4: ICM-20602; LGA-16_3x3mm_P0.5mm_LayoutBorder3x5y
U5: SHTC3; Sensirion_DFN-4-1EP_2x2mm_P1mm_EP0.7x1.6mm
U6: MIC5219-3.3YM5; SOT-23-5
U7: MCP73831-2-OT; SOT-23-5
U8: LCD; LCD-ST7789-1.54-12PINS
Y1: Crystal_Small; R_1206_3216Metric

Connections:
+3.3VA: C4.2, R3.2, U1.1 (VDDA), U1.3 (VDDA3P3), U1.4 (VDDA3P3), U1.19 (VDD3P3_RTC), U1.37 (VDD3P3_CPU), U1.43 (VDDA), U1.46 (VDDA)
+3V3: BZ1.1 (-), C3.1, C5.1, C6.1, C7.1, C11.1, C15.1, C16.1, D6.1 (K), R2.1, R3.1, R4.1, R7.1, R13.1, R18.1, U2.8 (VDD), U3.4 (V3), U3.16 (VCC), U4.1 (VDDIO), U4.16 (VDD), U5.1 (VDD), U6.5 (OUT), U8.3 (LEDA), U8.4 (VDD)
+BATT: C12.1, C13.1, J2.1, Q1.3 (D), R14.1, U7.3 (VBAT)
/BAT_DET: C14.1, R14.2, R15.1, U1.6 (SENSOR_CAPP)
/BUZZ: Q5.1 (G), R19.1, U1.14 (IO25)
/CH340_DTR: Q2.1 (E1), R17.2, U3.13 (~DTR)
/CH340_RTS: Q2.4 (E2), R16.1, U3.14 (~RTS)
/CH340_RXD: U1.41 (U0TXD/IO1), U3.3 (RXD)
/CH340_TXD: U1.40 (U0RXD/IO3), U3.2 (TXD)
/CHG_DET: R12.1, R13.2, U1.7 (SENSOR_CAPN), U7.1 (STAT)
/ESP_BOOT: Q2.6 (C1), U1.23 (IO0)
/ESP_EN: C8.1, Q2.3 (C2), R7.2, TP1.1, U1.9 (EN)
/GPIO2: U1.22 (IO2), U8.7 (D/C)
/GPIO4: U1.24 (IO4), U8.11 (RESET)
/GPIO5: SW5.2, U1.34 (IO5)
/GPIO9: U1.28 (SD2/IO9), U2.6 (SCL)
/GPIO10: U1.29 (SD3/IO10), U2.5 (SDA)
/GPIO12: Q6.1 (G), R20.2, U1.18 (IO12)
/GPIO13: R2.2, U1.20 (IO13), U2.7 (CLKO)
/GPIO14: U1.17 (IO14), U2.3 (~INT)
/GPIO15: U1.21 (IO15), U5.2 (SCL)
/GPIO18: U1.35 (IO18), U8.9 (SCL)
/GPIO19: U1.38 (IO19), U5.3 (SDA)
/GPIO21: D2.2 (A), U1.42 (IO21)
/GPIO23: U1.36 (IO23), U8.10 (SDA)
/GPIO27: D4.2 (A), R18.2, U1.16 (IO27)
/GPIO32: U1.12 (IO32), U4.3 (SDA/SDI)
/GPIO33: U1.13 (IO33), U4.2 (SCL/SPC)
/GPIO34: U1.10 (IO34), U4.6 (INT)
/GPIO35: SW2.2, U1.11 (IO35)
/KEY1_RAW: D3.1 (K), D4.1 (K), SW1.2
/KEY3: SW3.2, U1.39 (IO22)
/KEY4: SW4.2, U1.15 (IO26)
/SENSOR_VN: U1.8 (SENSOR_VN)
/SENSOR_VP: U1.5 (SENSOR_VP)
/USB_PWR_DM: J1.A7 (D-), J1.B7 (D-), U3.6 (UD-)
/USB_PWR_DP: J1.A6 (D+), J1.B6 (D+), U3.5 (UD+)
/VCC_SYS: Q4.2 (S), U6.1 (IN), U6.3 (EN)
/VCC_SYS_IN: D1.1 (K), Q1.2 (S), Q4.3 (D), R6.1
GND: C1.1, C2.1, C3.2, C4.1, C5.2, C6.2, C7.2, C8.2, C9.1, C10.2, C11.2, C12.2, C13.2, C14.2, C15.2, C16.2, J1.A1 (GND), J1.A12 (GND), J1.B1 (GND), J1.B12 (GND), J1.S1 (SHIELD), J2.2, Q3.2 (S), Q5.2 (S), Q6.2 (S), R1.2, R5.2, R8.1, R9.2, R10.2, R11.2, R15.2, R19.2, R20.1, SW1.1, SW2.1, SW3.1, SW4.1, SW5.1, U1.49 (GND), U3.1 (GND), U4.8 (FSYNC), U4.9 (GND), U4.10 (GND), U4.11 (GND), U4.12 (GND), U4.13 (GND), U4.15 (GND), U5.4 (VSS), U6.2 (GND), U7.2 (VSS), U8.1 (GND), U8.5 (GND), U8.6 (GND), U8.8 (CS), U8.12 (GND)
unnamed: AE1.1 (A), U1.2 (LNA_IN)
unnamed: BZ1.2 (+), D6.2 (A), Q5.3 (D)
unnamed: C1.2, U2.1 (OSCI), Y1.2
unnamed: C2.2, U2.2 (OSCO), Y1.1
unnamed: C10.1, U6.4 (BP)
unnamed: D2.1 (K), Q3.1 (G), R5.1
unnamed: D3.2 (A), Q3.3 (D), Q4.1 (G), R6.2
unnamed: D5.1 (K), R12.2
unnamed: J1.A5 (CC1), R10.1
unnamed: J1.B5 (CC2), R9.1
unnamed: Q2.2 (B1), R16.2
unnamed: Q2.5 (B2), R17.1
unnamed: Q6.3 (D), R21.1
unnamed: R1.1, U4.4 (SAO/SD0)
unnamed: R4.2, U4.5 (~CS)
unnamed: R8.2, U7.5 (PROG)
unnamed: R21.2, U8.2 (LEDK)
VBUS: C9.2, D1.2 (A), D5.2 (A), J1.A4 (VBUS), J1.A9 (VBUS), J1.B4 (VBUS), J1.B9 (VBUS), Q1.1 (G), R11.1, U7.4 (VDD)

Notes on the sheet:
MPU
pins 34/35/36/37/38/39 input only
5.0V
RTC&SENSOR
3.7V-4.2V
GPIO12: must be low when boot(flash voltage) GPIO5: must be high when boot GPIO14: pull up internal
XTerminal
MCU
USB
PWR
IOs
boot: 0:download 1:normalboot
TFT
CS: 0:spi 1:iic

Board: 2 copper layers, 68 parts (1 on the bottom side), 56 nets, no tracks yet.

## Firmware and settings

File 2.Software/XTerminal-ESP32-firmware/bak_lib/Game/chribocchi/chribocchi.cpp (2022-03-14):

#include "common.h"

// #if ARDUBOY_LIB_VER != 10101
// #error
// #endif // It may work even if you use other version.

/*  Defines  */

enum MODE {
    LOGO_MODE = 0,
    TITLE_MODE,
    GAME_MODE
};

/*  Typedefs  */

typedef struct {
    void(*initFunc)(void);
    bool(*updateFunc)(void);
    void(*drawFunc)(void);
} MODULE_FUNCS;

/*  Global Variables  */

MyArduboy arduboy;

/*  Local Variables  */

static const MODULE_FUNCS moduleTable[] = {
    { initLogo,  updateLogo,  drawLogo },
    { initTitle, updateTitle, drawTitle },
    { initGame,  updateGame,  drawGame },
};

static MODE mode = LOGO_MODE;

/*  For Debugging  */

#ifdef DEBUG
bool    dbgPrintEnabled = true;
char    dbgRecvChar = '\0';
uint8_t dbgCaptureMode = 0;

static void dbgCheckSerialRecv(void) {
    int recv;
    while ((recv = Serial.read()) != -1) {
        switch (recv) {
        case 'd':
            dbgPrintEnabled = !dbgPrintEnabled;
            Serial.print("Debug output ");
            Serial.println(dbgPrintEnabled ? "ON" : "OFF");
            break;
        case 'c':
            dbgCaptureMode = 1;
            break;
        case 'C':
            dbgCaptureMode = 2;
            break;
        }
        if (recv >= ' ' && recv <= '~') dbgRecvChar = recv;
    }
}

static void dbgScreenCapture() {
    if (dbgCaptureMode) {
        Serial.write((const uint8_t *)arduboy.getBuffer(), WIDTH * HEIGHT / 8);
        if (dbgCaptureMode == 1) dbgCaptureMode = 0;
    }
}
#endif

/*---------------------------------------------------------------------------*/

static void setup()
{
#ifdef DEBUG
    Serial.begin(115200);
#endif
    arduboy.beginNoLogo();
    arduboy.setFrameRate(60);
    moduleTable[LOGO_MODE].initFunc();
}

static void loop()
{
#ifdef DEBUG
    dbgCheckSerialRecv();
#endif
    if (!(arduboy.nextFrame())) return;
    bool isDone = moduleTable[mode].updateFunc();
    moduleTable[mode].drawFunc();
#ifdef DEBUG
    dbgScreenCapture();
    dbgRecvChar = '\0';
#endif
    arduboy.display();
    if (isDone) {
        mode = (mode == TITLE_MODE) ? GAME_MODE : TITLE_MODE;
        moduleTable[mode].initFunc();
        dprint("mode=");
        dprintln(mode);
    }
}

static void exit()
{
    
}

#include "../GamePrivate.h"

void GameRegister_chrbocchi(uint8_t gameID)
{
    GamePage.PageRegister(gameID, setup, loop, exit, NULL);
}

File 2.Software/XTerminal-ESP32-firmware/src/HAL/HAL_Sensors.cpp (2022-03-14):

#include "HAL.h"
#include <Wire.h>

// float gvar.bmp_pressure;
// float gvar.bmp_altitude;


#if defined(USE_BMP280)
#include <Adafruit_BMP280.h>
Adafruit_BMP280 bmp;
float bmp_temp;


void bmp_get()
{
    gvar.bmp_pressure = bmp.readPressure()/1000;
    // gvar.bmp_pressure = 0;
    gvar.bmp_altitude = bmp.readAltitude(1013.25);
    bmp_temp = bmp.readTemperature();

    Serial.print(F("Temperature = "));
    Serial.print(bmp_temp);
    Serial.println(" *C");

    Serial.print(F("Pressure = "));
    Serial.print(gvar.bmp_pressure);
    Serial.println(" Pa");

    Serial.print(F("Approx altitude = "));
    Serial.print(gvar.bmp_altitude); /* Adjusted to local forecast! */
    Serial.println(" m");
}
#endif

#if defined(USE_MAX30102)
#include "MAX30105.h"
#include "heartRate.h"
#include "spo2_algorithm.h"

float beatsPerMinute;
float beatAvg;
long irValue;
long redValue;
long greenValue;

MAX30105 particleSensor;
uint32_t irBuffer[100];   // infrared LED sensor data
uint32_t redBuffer[100];  // red LED sensor data
long samplesTaken = 0;    // Counter for calculating the Hz or read rate
long unblockedValue;      // Average IR at power up
long startTime;           // Used to calculate measurement rate
int32_t bufferLength;     // data length
int32_t spo2;             // SPO2 value
int8_t validSPO2;         // indicator to show if the SPO2 calculation is valid
int32_t heartRate;        // heart rate value
int8_t validHeartRate;    // indicator to show if the heart rate calculation is valid
const byte RATE_SIZE = 5; // Increase this for more averaging. 4 is good.
byte rates[RATE_SIZE];    // Array of heart rates
byte rateSpot = 0;
long lastBeat = 0;

void spo_init()
{

    byte ledBrightness = 60; // Options: 0=Off to 255=50mA
    byte sampleAverage = 4;  // Options: 1, 2, 4, 8, 16, 32
    byte ledMode = 2;        // Options: 1 = Red only, 2 = Red + IR, 3 = Red + IR + Green
    byte sampleRate = 100;   // Options: 50, 100, 200, 400, 800, 1000, 1600, 3200
    int pulseWidth = 411;    // Options: 69, 118, 215, 411
    int adcRange = 4096;     // Options: 2048, 4096, 8192, 16384

    particleSensor.setup(ledBrightness, sampleAverage, ledMode, sampleRate, pulseWidth, adcRange);

    bufferLength = 100; // buffer length of 100 stores 4 seconds of samples running at 25sps

    // read the first 100 samples, and determine the signal range
    for (byte i = 0; i < bufferLength; i++)
    {
        while (particleSensor.available() == false) // do we have new data?
            particleSensor.check();                 // Check the sensor for new data

        redBuffer[i] = particleSensor.getRed();
        irBuffer[i] = particleSensor.getIR();
        particleSensor.nextSample(); // We're finished with this sample so move to next sample

        Serial.print(F("red="));
        Serial.print(redBuffer[i], DEC);
        Serial.print(F(", ir="));
        Serial.println(irBuffer[i], DEC);
    }

    // calculate heart rate and SpO2 after first 100 samples (first 4 seconds of samples)
    maxim_heart_rate_and_oxygen_saturation(irBuffer, bufferLength, redBuffer, &spo2, &validSPO2, &heartRate, &validHeartRate);
}

void spo_get()
{

    // Continuously taking samples from MAX30102.  Heart rate and SpO2 are calculated every 1 second
    while (1)
    {
        // dumping the first 25 sets of samples in the memory and shift the last 75 sets of samples to the top
        for (byte i = 25; i < 100; i++)
        {
            redBuffer[i - 25] = redBuffer[i];
            irBuffer[i - 25] = irBuffer[i];
        }

        // take 25 sets of samples before calculating the heart rate.
        for (byte i = 75; i < 100; i++)
        {
            while (particleSensor.available() == false) // do we have new data?
                particleSensor.check();                 // Check the sensor for new data

            // digitalWrite(readLED, !digitalRead(readLED)); // Blink onboard LED with every data read

            redBuffer[i] = particleSensor.getRed();
            irBuffer[i] = particleSensor.getIR();
            particleSensor.nextSample(); // We're finished with this sample so move to next sample

            // send samples and calculation result to terminal program through UART
            Serial.print(F("red="));
            Serial.print(redBuffer[i], DEC);
            Serial.print(F(", ir="));
            Serial.print(irBuffer[i], DEC);

            Serial.print(F(", HR="));
            Serial.print(heartRate, DEC);

            Serial.print(F(", HRvalid="));
            Serial.print(validHeartRate, DEC);

            Serial.print(F(", SPO2="));
            Serial.print(spo2, DEC);

            Serial.print(F(", SPO2Valid="));
            Serial.println(validSPO2, DEC);
        }

        // After gathering 25 new samples recalculate HR and SP02
        maxim_heart_rate_and_oxygen_saturation(irBuffer, bufferLength, redBuffer, &spo2, &validSPO2, &heartRate, &validHeartRate);
    }
}

void temp_get()
{
    float temperature = particleSensor.readTemperature();

    Serial.print("temperatureC=");
    Serial.print(temperature, 4);
}

void hr_init()
{
    particleSensor.setup();                    // Configure sensor with default settings
    particleSensor.setPulseAmplitudeRed(0x0A); // Turn Red LED to low to indicate sensor is running
    particleSensor.setPulseAmplitudeGreen(0);  // Turn off Green LED
}

void hr_get()
{
    irValue = particleSensor.getIR();
    redValue = particleSensor.getRed();
    // greenValue = particleSensor.getGreen();

    if (checkForBeat(irValue) == true)
    {
        // We sensed a beat!
        long delta = millis() - lastBeat;
        lastBeat = millis();

        beatsPerMinute = 60 / (delta / 1000.0);

        if (beatsPerMinute < 255 && beatsPerMinute > 35)
        {
            rates[rateSpot++] = (byte)beatsPerMinute; // Store this reading in the array
            rateSpot %= RATE_SIZE;                    // Wrap variable

            // Take average of readings
            beatAvg = 0;
            for (byte x = 0; x < RATE_SIZE; x++)
                beatAvg += rates[x];
            beatAvg /= RATE_SIZE;
        }
    }

    // Serial.print("IR=");
    // Serial.print(irValue);
    // Serial.print(", BPM=");
    // Serial.print(beatsPerMinute);
    // Serial.print(", Avg BPM=");
    // Serial.print(beatAvg);

    // // if (irValue < 50000)
    // //     Serial.print(" No finger?");

    // Serial.println();
}
#endif

void HAL::sensors_init()
{
#if defined(USE_MAX30102)
    if (!particleSensor.begin(Wire1, I2C_SPEED_FAST))
    {
        Serial.println("MAX30105 was not found. Please check wiring/power. ");
    }

    hr_init();
#endif
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

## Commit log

2022-03-14 intergrate partments
    [PCB外壳.SLDPRT, XSense.step, c-2295018-2-b-3d.stp.SLDPRT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]
2022-03-14 update readme && merge firmware
    [AudioExtendBoard-B_Cu.gbr, AudioExtendBoard-B_Mask.gbr, AudioExtendBoard-B_Paste.gbr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]
